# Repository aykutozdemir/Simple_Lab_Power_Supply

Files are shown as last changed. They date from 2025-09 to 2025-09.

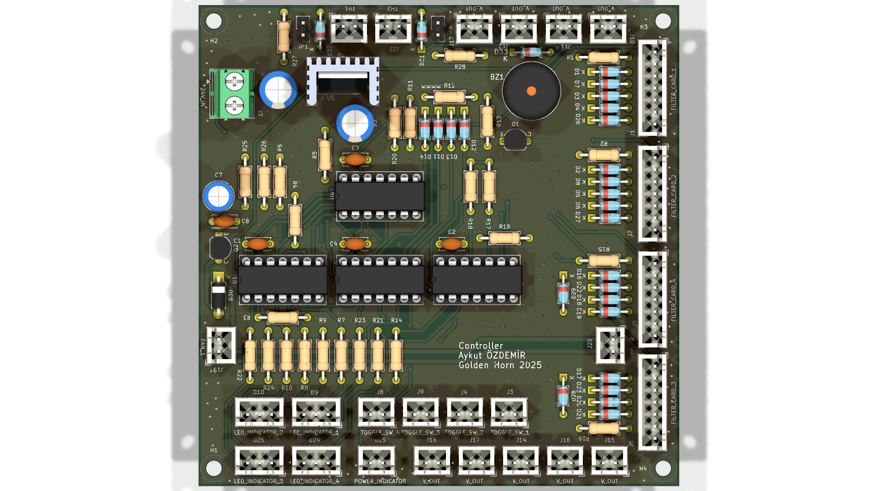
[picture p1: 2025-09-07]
Controller/generated/3d/Controller_3d_top.png

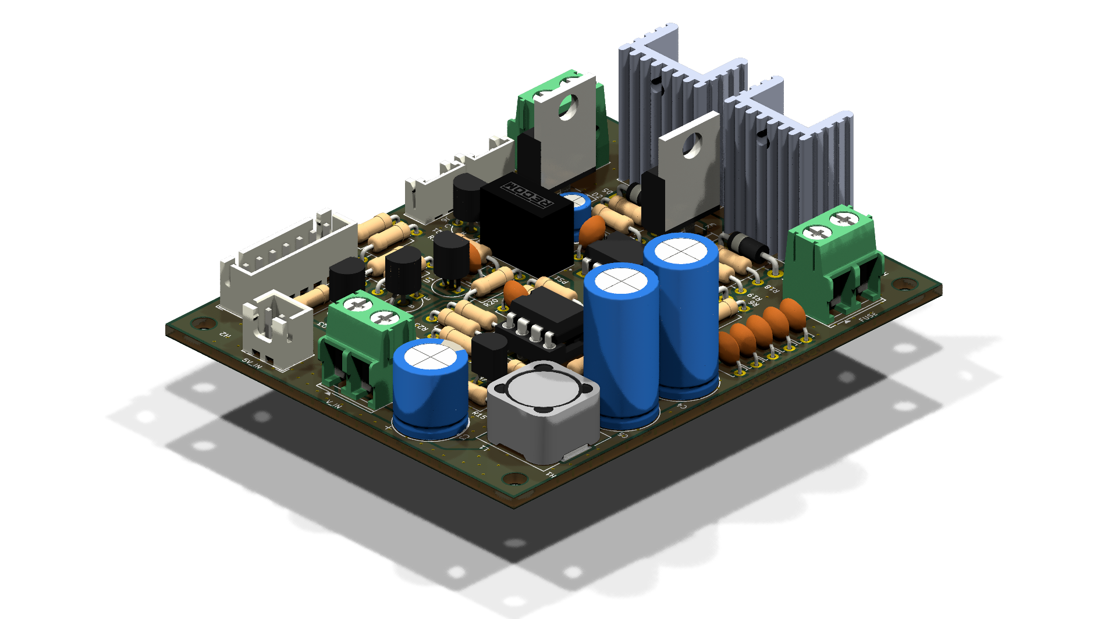
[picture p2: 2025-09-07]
Protection/generated/3d/Protection_3d_back-right-up.png

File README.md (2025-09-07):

### Simple Lab Power Supply (4-Channel)

A compact four-channel bench power supply project with dedicated controller, protection, and current-sensing boards, plus a printable enclosure and front panel components. Repository: [`aykutozdemir/Simple_Lab_Power_Supply`](https://github.com/aykutozdemir/Simple_Lab_Power_Supply).

### Features
- **Four independent channels**: adjustable and monitorable per-channel output
- **Dedicated protection**: over-current/short-circuit protection board
- **Current sensing**: separate current sensor design for precise measurement
- **Printable enclosure**: parametric SCAD and exported STLs for all case parts
- **Fabrication-ready**: gerbers, BOMs, PDFs, and 3D previews included

### Repository layout
- `Controller/`: KiCad project for the main control PCB
  - `generated/gerbers/`: fabrication files
  - `generated/bom/`: BOM in CSV/HTML/PDF
  - `generated/pdf/`: PCB and schematic PDFs
  - `generated/3d/`: 3D renders and board STEP/STL
- `Protection/`: KiCad project for the protection PCB
  - `generated/` mirrors the structure above
- `Current_Sensor/`: KiCad project for the current sensor
- `3D/`: mechanical assets and enclosure
  - `exports/`: printable panels and enclosure parts (`front.stl`, `back.stl`, `left.stl`, `right.stl`, `top.stl`, `bottom.stl`, `mid.stl`)
  - subfolders for off-the-shelf or custom components (banana jacks, fan, sockets, switches, knobs, etc.)

### Quick start
1) Open electronics in KiCad (KiCad 7+ recommended):
   - `Controller/Controller.kicad_pro`
   - `Protection/Protection.kicad_pro`
   - `Current_Sensor/Current_Sensor.kicad_pro`
2) Fabrication files:
   - Controller gerbers: `Controller/generated/gerbers/`
   - Protection gerbers: `Protection/generated/gerbers/`
   - BOMs: `Controller/generated/bom/Controller_bom.*`, `Protection/generated/bom/Protection_bom.*`
   - PDFs (schematic/PCB): see `generated/pdf/`
3) Enclosure and front panel:
   - Print from `3D/exports/*.stl`
   - Optional components located in subfolders (e.g., `3D/banana/banana.stl`, `3D/pot/pot.stl`, `3D/fan/fan.stl`)

### 3D printing guidance
- Material: PLA or PETG (PETG recommended for heat resistance)
- Layer height: 0.2 mm (typ.)
- Infill: 15–25% grid/gyroid for panels; 35–50% for brackets
- Walls: 3–4 perimeters; 4–6 top/bottom layers
- Orientation: print panels flat; brackets with load-bearing axis aligned; check STL previews in `3D/exports/`

### Front panel notes
- Displays and meters mount to the `front.stl` panel. Matching cutouts are modeled in the exported panel.
- Banana connectors: use `3D/banana/banana.stl`. In the assembled view, place two banana connectors per multimeter, horizontally below the displays, visible from front. Front panel hole x-offsets at ±12 mm and z at `box_height*4/6 - multimeter_height/2 - 25`. Place connectors at y slightly in front of the front panel (e.g., `box_depth + 1`) and rotate `[-90, 0, 0]` for insertion alignment [[memory:6634135]].

### Electrical overview
- Controller board manages channel outputs, measurement, and user interface.
- Protection board implements fast over-current/short protection and isolation where needed.
- Current sensor board provides per-channel current measurement with appropriate scaling.
- See the comprehensive PDFs in `Controller/generated/pdf/` and `Protection/generated/pdf/` for signal names and interfaces.

### Fabrication and assembly
1) Order PCBs using the gerbers in each project’s `generated/gerbers/` directory.
2) Source parts from the BOMs (`generated/bom/`). Check packages/footprints against PDFs.
3) Solder SMD/TH components as per schematics.
4) Test each board independently before system integration.
5) Assemble enclosure:
   - Dry-fit `front`, `back`, `left`, `right`, `top`, `bottom`, and `mid` panels.
   - Install switches, sockets, fuses, fan, pots/knobs, and banana jacks.
   - Route wiring according to schematics; keep high-current and low-noise paths separated.

### Safety
- Mains voltages and high currents can be hazardous. Verify isolation, fusing, and protective earth where applicable.
- Use appropriate gauge wiring, strain relief, and insulation. Validate thermal performance under load.

### Contributing
- Issues and pull requests are welcome on GitHub: `https://github.com/aykutozdemir/Simple_Lab_Power_Supply`.
- For changes that affect the enclosure, export updated STLs to `3D/exports/` and include screenshots/renders.
- For PCB edits, regenerate `generated/` assets (BOM, PDFs, gerbers) so reviewers can diff artifacts.

### License
No license file is included yet. If you intend to reuse or distribute, please open an issue to clarify licensing, or add a `LICENSE` file.

### Credits
Design and repository maintained by Aykut Ozdemir. See the GitHub repository for history and updates: [`Simple_Lab_Power_Supply`](https://github.com/aykutozdemir/Simple_Lab_Power_Supply).

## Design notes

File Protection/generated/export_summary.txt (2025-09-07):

KiCad Export Summary
===================
Project: Protection
Export Date: Sun Sep  7 02:46:42 PM +03 2025
Output Folder: generated

Generated Files:
================
  3d/Protection_3d_back-left.png
  3d/Protection_3d_back-left-up.png
  3d/Protection_3d_back.png
  3d/Protection_3d_back-right.png
  3d/Protection_3d_back-right-up.png
  3d/Protection_3d_bottom-left.png
  3d/Protection_3d_bottom.png
  3d/Protection_3d_bottom-right.png
  3d/Protection_3d_front-left.png
  3d/Protection_3d_front-left-up.png
  3d/Protection_3d_front.png
  3d/Protection_3d_front-right.png
  3d/Protection_3d_front-right-up.png
  3d/Protection_3d_left.png
  3d/Protection_3d_right.png
  3d/Protection_3d_top-left.png
  3d/Protection_3d_top-left-up.png
  3d/Protection_3d_top.png
  3d/Protection_3d_top-right.png
  3d/Protection_3d_top-right-up.png
  3d/Protection_board.step
  3d/Protection_board.stl
  3d/Protection_full.step
  3d/Protection_full.stl
  bom/Protection_bom.csv
  bom/Protection_bom.html
  bom/Protection_bom.pdf
  export_summary.txt
  gerbers/Protection-B_Adhesive.gba
  gerbers/Protection-B_Courtyard.gbr
  gerbers/Protection-B_Cu.gbl
  gerbers/Protection-B_Fab.gbr
  gerbers/Protection-B_Mask.gbs
  gerbers/Protection-B_Paste.gbp
  gerbers/Protection-B_Silkscreen.gbo
  gerbers/Protection.drl
  gerbers/Protection-Edge_Cuts.gm1
  gerbers/Protection-F_Adhesive.gta
  gerbers/Protection-F_Courtyard.gbr
  gerbers/Protection-F_Cu.gtl
  gerbers/Protection-F_Fab.gbr
  gerbers/Protection-F_Mask.gts
  gerbers/Protection-F_Paste.gtp
  gerbers/Protection-F_Silkscreen.gto
  gerbers/Protection_gerbers.zip
  gerbers/Protection-job.gbrjob
  gerbers/Protection-Margin.gbr
  gerbers/Protection-User_1.gbr
  gerbers/Protection-User_2.gbr
  gerbers/Protection-User_3.gbr
  gerbers/Protection-User_4.gbr
  gerbers/Protection-User_Comments.gbr
  gerbers/Protection-User_Drawings.gbr
  gerbers/Protection-User_Eco1.gbr
  gerbers/Protection-User_Eco2.gbr
  pdf/pcb/Protection_B.Cu.pdf
  pdf/pcb/Protection_B.SilkS.pdf
  pdf/pcb/Protection_F.Cu.pdf
  pdf/pcb/Protection_F.SilkS.pdf
  pdf/Protection_comprehensive.pdf
  pdf/schematic/Protection.pdf

Folder Structure:
=================
/home/aykut/Dropbox/Developments/KiCad/Simple_Lab_Power_Supply/Protection/generated
  3d
  bom
  gerbers
  pdf
  pdf/pcb
  pdf/schematic

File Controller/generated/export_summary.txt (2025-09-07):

KiCad Export Summary
===================
Project: Controller
Export Date: Wed Aug 27 04:48:48 PM +03 2025
Output Folder: generated

Generated Files:
================
  3d/Controller_3d_back-left.png
  3d/Controller_3d_back-left-up.png
  3d/Controller_3d_back.png
  3d/Controller_3d_back-right.png
  3d/Controller_3d_back-right-up.png
  3d/Controller_3d_bottom-left.png
  3d/Controller_3d_bottom.png
  3d/Controller_3d_bottom-right.png
  3d/Controller_3d_front-left.png
  3d/Controller_3d_front-left-up.png
  3d/Controller_3d_front.png
  3d/Controller_3d_front-right.png
  3d/Controller_3d_front-right-up.png
  3d/Controller_3d_left.png
  3d/Controller_3d_right.png
  3d/Controller_3d_top-left.png
  3d/Controller_3d_top-left-up.png
  3d/Controller_3d_top.png
  3d/Controller_3d_top-right.png
  3d/Controller_3d_top-right-up.png
  3d/Controller_board.step
  3d/Controller_board.stl
  3d/Controller_full.step
  3d/Controller_full.stl
  bom/Controller_bom.csv
  bom/Controller_bom.html
  bom/Controller_bom.pdf
  export_summary.txt
  gerbers/Controller-B_Adhesive.gba
  gerbers/Controller-B_Courtyard.gbr
  gerbers/Controller-B_Cu.gbl
  gerbers/Controller-B_Fab.gbr
  gerbers/Controller-B_Mask.gbs
  gerbers/Controller-B_Paste.gbp
  gerbers/Controller-B_Silkscreen.gbo
  gerbers/Controller.drl
  gerbers/Controller-Edge_Cuts.gm1
  gerbers/Controller-F_Adhesive.gta
  gerbers/Controller-F_Courtyard.gbr
  gerbers/Controller-F_Cu.gtl
  gerbers/Controller-F_Fab.gbr
  gerbers/Controller-F_Mask.gts
  gerbers/Controller-F_Paste.gtp
  gerbers/Controller-F_Silkscreen.gto
  gerbers/Controller_gerbers.zip
  gerbers/Controller-job.gbrjob
  gerbers/Controller-Margin.gbr
  gerbers/Controller-User_1.gbr
  gerbers/Controller-User_2.gbr
  gerbers/Controller-User_3.gbr
  gerbers/Controller-User_4.gbr
  gerbers/Controller-User_Comments.gbr
  gerbers/Controller-User_Drawings.gbr
  gerbers/Controller-User_Eco1.gbr
  gerbers/Controller-User_Eco2.gbr
  pdf/Controller_comprehensive.pdf
  pdf/pcb/Controller_B.Cu.pdf
  pdf/pcb/Controller_B.SilkS.pdf
  pdf/pcb/Controller_F.Cu.pdf
  pdf/pcb/Controller_F.SilkS.pdf
  pdf/schematic/Controller.pdf

Folder Structure:
=================
/home/aykut/Dropbox/Developments/KiCad/Simple_Lab_Power_Supply/Controller/generated
  3d
  bom
  gerbers
  pdf
  pdf/pcb
  pdf/schematic

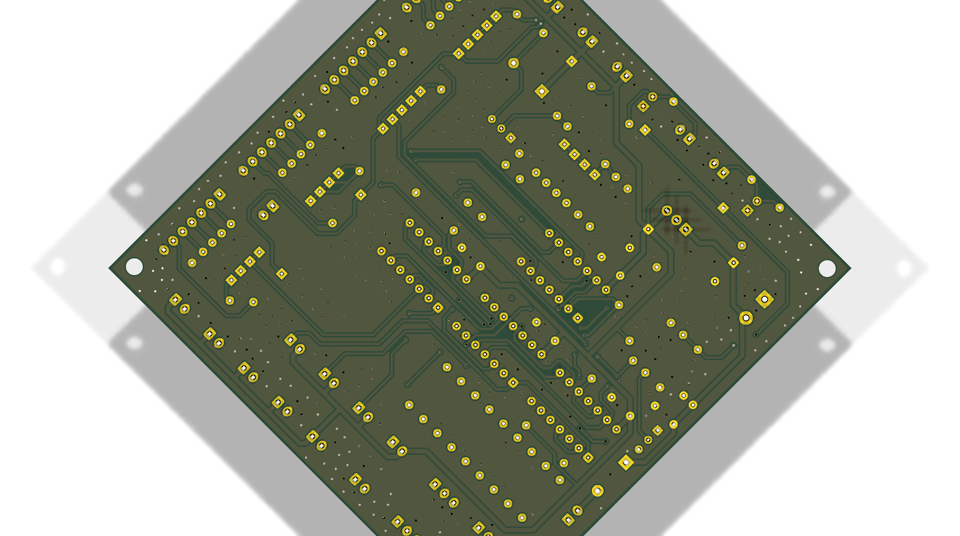
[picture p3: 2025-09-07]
Controller/generated/3d/Controller_3d_bottom-left.png

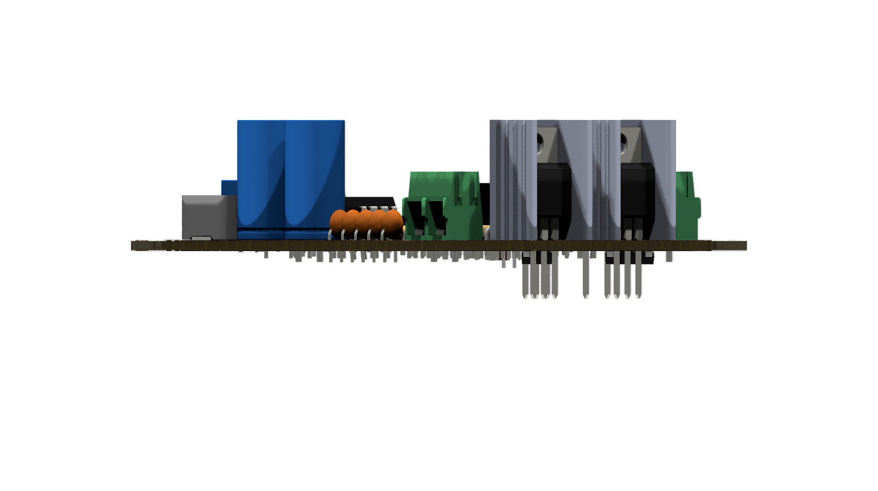
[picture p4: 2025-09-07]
Protection/generated/3d/Protection_3d_front-left.png

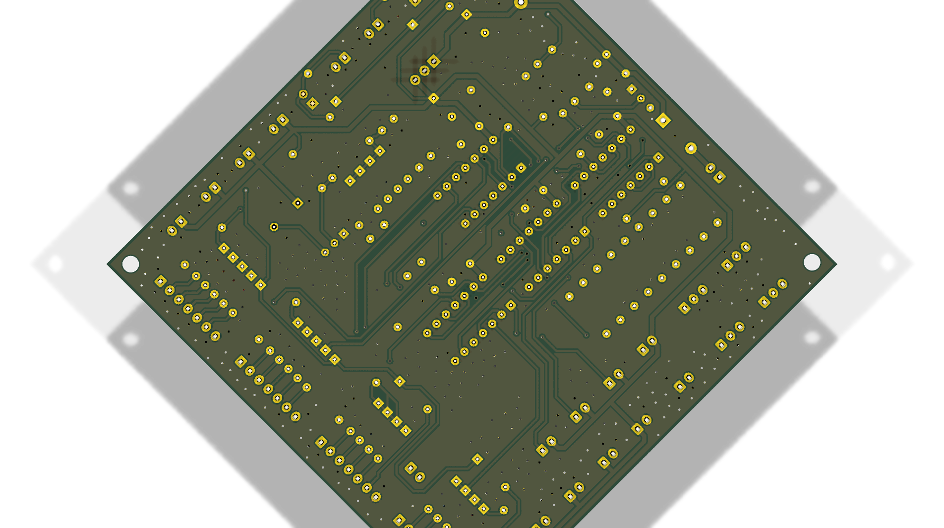
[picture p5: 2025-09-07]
Controller/generated/3d/Controller_3d_bottom-right.png

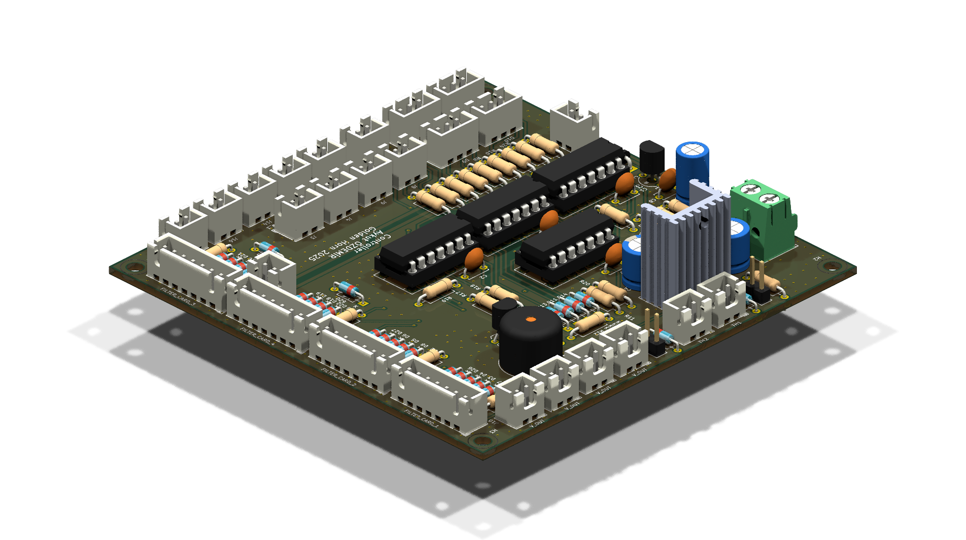
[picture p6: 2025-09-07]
Controller/generated/3d/Controller_3d_back-left-up.png

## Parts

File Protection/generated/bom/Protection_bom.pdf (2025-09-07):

# Bill of Materials

## Protection

Export Date: Sun Sep 7 02:46:40 PM +03 2025 | Total Components: 44
Reference | Value | Footprint | Quantity | Rating/Spec
C10 | 100p | Capacitor_THT:C_Disc_D5.0mm_W2.5mm_P5.00mm | 1 | 50V
C9 | 1n | Capacitor_THT:C_Disc_D5.0mm_W2.5mm_P5.00mm | 1 | 50V
C8 | 10n | Capacitor_THT:C_Disc_D5.0mm_W2.5mm_P5.00mm | 1 | 50V
C1,C2,C7,C11,C13,C15 | 100n | Capacitor_THT:C_Disc_D5.0mm_W2.5mm_P5.00mm | 6 | 50V
C6 | 1u | Capacitor_THT:C_Disc_D5.0mm_W2.5mm_P5.00mm | 1 | 50V
C14 | 100u | Capacitor_THT:CP_Radial_D5.0mm_P2.50mm | 1 | 25V
C3 | 330u | Capacitor_THT:CP_Radial_D10.0mm_P5.00mm | 1 | 50V
C4,C5 | 470u | Capacitor_THT:C_Radial_D10.0mm_H20.0mm_P5.00mm | 2 | 50V
J3 | 5V_IN | Connector_JST:JST_XH_B2B-XH-A_1x02_P2.50mm_Vertical | 1
F1 | 10A | TerminalBlock_Phoenix:TerminalBlock_Phoenix_PT-1,5-2-5.0-H_1x02_P5.00mm_Horizontal | 1
R19,R21 | 10 | Resistor_THT:R_Axial_DIN0207_L6.3mm_D2.5mm_P10.16mm_Horizontal | 2
D3,D5 | 15V | Diode_THT:D_DO-41_SOD81_P10.16mm_Horizontal | 2
R11 | 120 | Resistor_THT:R_Axial_DIN0207_L6.3mm_D2.5mm_P10.16mm_Horizontal | 1
R20 | 270 | Resistor_THT:R_Axial_DIN0207_L6.3mm_D2.5mm_P10.16mm_Horizontal | 1
R1,R6,R10,R12,R13,R15,R17 | 1k | Resistor_THT:R_Axial_DIN0207_L6.3mm_D2.5mm_P10.16mm_Horizontal | 7
R7,R8 | 10k | Resistor_THT:R_Axial_DIN0207_L6.3mm_D2.5mm_P10.16mm_Horizontal | 2 | %1
R14,R16,R22,R24 | 10k | Resistor_THT:R_Axial_DIN0207_L6.3mm_D2.5mm_P10.16mm_Horizontal | 4
R9,R18 | 47k | Resistor_THT:R_Axial_DIN0207_L6.3mm_D2.5mm_P10.16mm_Horizontal | 2
R23 | 100k | Resistor_THT:R_Axial_DIN0207_L6.3mm_D2.5mm_P10.16mm_Horizontal | 1
R25 | 0/0/0/10k | Resistor_THT:R_Axial_DIN0207_L6.3mm_D2.5mm_P10.16mm_Horizontal | 1 | %1
R5 | 150k/150k/100k/3V Zener | Resistor_THT:R_Axial_DIN0207_L6.3mm_D2.5mm_P10.16mm_Horizontal | 1 | %1
R2 | 150k/150k/130k/33k | Resistor_THT:R_Axial_DIN0207_L6.3mm_D2.5mm_P10.16mm_Horizontal | 1 | %1
Q1,Q3-Q5 | 2N3904 | PCM_Package_TO_SOT_THT_AKL:TO-92_Inline_Wide_EBC | 4
D4 | 3.9V/5.6V/13V/27V | Diode_THT:D_DO-41_SOD81_P10.16mm_Horizontal | 1
R4 | 30k/120k/330k/1k | Resistor_THT:R_Axial_DIN0207_L6.3mm_D2.5mm_P10.16mm_Horizontal | 1 | %1

Bill of Materials - Protection

Reference | Value | Footprint | Quantity | Rating/Spec
C12 | 4u7 | Capacitor_SMD:C_1206_3216Metric_Pad1.33x1.80mm_HandSolder | 1 | 50V
L1 | 4u7 | Inductor_SMD:L_12x12mm_H8mm | 1 | 15A
R3 | 68k/180k/560k/330k | Resistor_THT:R_Axial_DIN0207_L6.3mm_D2.5mm_P10.16mm_Horizontal | 1 | %1
Q2 | BT152-800R | PCM_Package_TO_SOT_THT_AKL:TO-220-3_Vertical_KAG | 1
HS1,HS2 | Heatsink | Power_Module_Library:TO-220_Heatsink | 2
Q6,Q8 | IRF1404/IRFB4110 | PCM_Package_TO_SOT_THT_AKL:TO-220-3_Vertical_GDS | 2
J2,J6 | JST_02 | Connector_JST:JST_EH_B2B-EH-A_1x02_P2.50mm_Vertical | 2
J5 | JST_07 | Connector_JST:JST_XH_B7B-XH-A_1x07_P2.50mm_Vertical | 1
U2 | LM393 | PCM_Package_DIP_AKL:DIP-8_W7.62mm_Socket | 1
D2 | MBR1045 | PCM_Package_TO_SOT_THT_AKL:TO-220-2_Vertical_KA | 1
R26 | NC/NC/NC/3k9 | Resistor_THT:R_Axial_DIN0207_L6.3mm_D2.5mm_P10.16mm_Horizontal | 1 | %1
PS1 | ROE-0515S | Isolation_Trafo:CONV_ROE-0515S | 1
D1 | SMAJ5.0A/6.0A/13.0A/26A | PCM_Diode_SMD_AKL:D_SMA | 1
D6 | SMAJ5.0A/6.0A/18.0A/30A | PCM_Diode_SMD_AKL:D_SMA | 1
D7 | SMAJ5.0A/6.0A/18.0A/33A | PCM_Diode_SMD_AKL:D_SMA | 1
U1 | TL431LP | Package_TO_SOT_THT:TO-92_Inline | 1
U3 | TLP250 | Package_DIP:DIP-8_W7.62mm | 1
J1 | V_IN | TerminalBlock_Phoenix:TerminalBlock_Phoenix_PT-1,5-2-5.0-H_1x02_P5.00mm_Horizontal | 1
J4 | V_OUT | TerminalBlock_Phoenix:TerminalBlock_Phoenix_PT-1,5-2-5.0-H_1x02_P5.00mm_Horizontal | 1
Generated by KiCad Export System | Professional BOM Documentation

Bill of Materials - Protection

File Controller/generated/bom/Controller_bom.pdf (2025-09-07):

# Bill of Materials

## Controller

Export Date: Wed Aug 27 04:48:46 PM +03 2025 | Total Components: 26
Reference | Value | Footprint | Quantity | Rating/ Spec
C6 | 0.1u | Capacitor_THT:CP_Radial_Tantal_D5.5mm_P5.00mm | 1 | 63V
C1-C4,C8 | 100n | Capacitor_THT:C_Disc_D5.0mm_W2.5mm_P5.00mm | 5 | 50V
C5 | 0.33u | Capacitor_THT:CP_Radial_Tantal_D5.5mm_P5.00mm | 1 | 50V
C7 | 47u | Capacitor_THT:C_Radial_D6.3mm_H11.0mm_P2.50mm | 1 | 50V
R7-R10,R14,R21-R24 | 470 | Resistor_THT:R_Axial_DIN0207_L6.3mm_D2.5mm_P10.16mm_Horizontal | 9 | %1
R26 | 820 | Resistor_THT:R_Axial_DIN0207_L6.3mm_D2.5mm_P10.16mm_Horizontal | 1
R12 | 1k | Resistor_THT:R_Axial_DIN0207_L6.3mm_D2.5mm_P10.16mm_Horizontal | 1
R1,R2,R11,R13,R15,R16,R25 | 10k | Resistor_THT:R_Axial_DIN0207_L6.3mm_D2.5mm_P10.16mm_Horizontal | 7
R3-R6,R17-R20 | 10k | Resistor_THT:R_Axial_DIN0207_L6.3mm_D2.5mm_P10.16mm_Horizontal | 8 | %1
D30 | 1N4001 | PCM_Diode_THT_AKL:D_DO-41_SOD81_P7.62mm_Horizontal | 1
D1-D8,D11-D14,D16-D23,D26-D29,D31-D33 | 1N4148 | PCM_Diode_THT_AKL:D_DO-35_SOD27_P7.62mm_Horizontal | 27
Q1 | 2N3904 | PCM_Package_TO_SOT_THT_AKL:TO-92_Inline_Wide_EBC | 1
Q2 | 2N4401 | PCM_Package_TO_SOT_THT_AKL:TO-92_Inline_Wide_EBC | 1
R27,R28 | 4k7 | Resistor_THT:R_Axial_DIN0207_L6.3mm_D2.5mm_P10.16mm_Horizontal | 2
U3 | 74LS08 | Package_DIP:DIP-14_W7.62mm_Socket | 1
U1,U2 | 74LS74 | Package_DIP:DIP-14_W7.62mm_Socket | 2
U4 | 74LS86 | Package_DIP:DIP-14_W7.62mm_Socket | 1
BZ1 | Buzzer_5V | Buzzer_Beeper:Buzzer_12x9.5RM7.6 | 1
HS1 | Heatsink_Generic | Power_Module_Library:TO-220_Heatsink | 1
J3,J4,J8-J22 | JST_02 | Connector_JST:JST_XH_B2B-XH-A_1x02_P2.50mm_Vertical | 17
J1,J2,J5,J6 | JST_07 | Connector_JST:JST_XH_B7B-XH-A_1x07_P2.50mm_Vertical | 4
U5 | L7805CV | PCM_Package_TO_SOT_THT_AKL:TO-220-3_Vertical | 1
D15 | LED_5mm | Connector_JST:JST_XH_B2B-XH-A_1x02_P2.50mm_Vertical | 1
D9,D10,D24,D25 | LED_Dual_AKA | Connector_JST:JST_XH_B3B-XH-A_1x03_P2.50mm_Vertical | 4

Bill of Materials - Controller

Reference | Value | Footprint | Quantity | Rating/ Spec
J7 | Screw_Terminal_2_P5.00mm | TerminalBlock_Phoenix:TerminalBlock_Phoenix_PT-1,5-2-5.0-H_1x02_P5.00mm_Horizontal | 1
JP1,JP2 | ~ | Connector_PinHeader_2.54mm:PinHeader_1x02_P2.54mm_Vertical | 2
Generated by KiCad Export System | Professional BOM Documentation

Bill of Materials - Controller

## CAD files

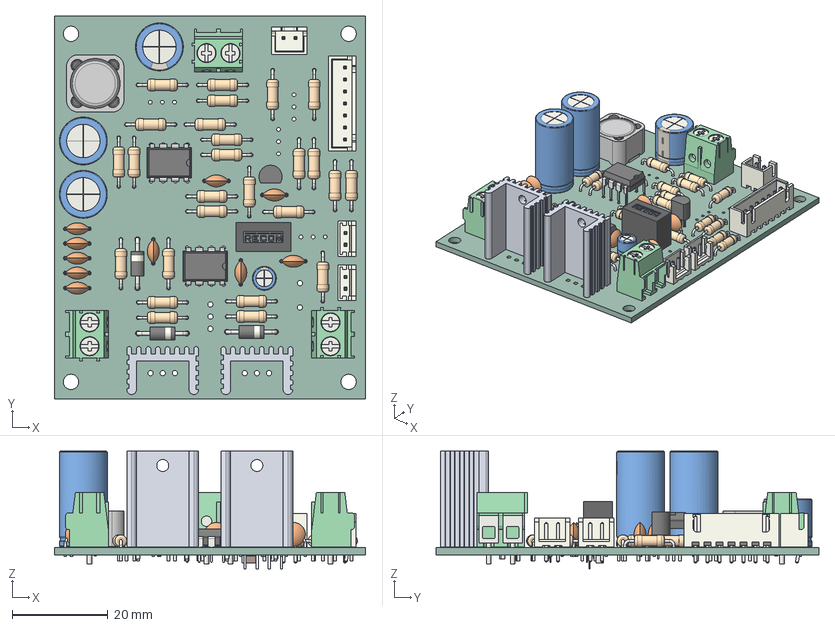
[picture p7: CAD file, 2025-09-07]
Protection/generated/3d/Protection_full.step
65.0 x 80.0 x 24.6 mm
D_DO-41_SOD81_P10.16mm_Horizontal x 3
CP_Radial_D10.0mm_P5.00mm
R_Axial_DIN0207_L6.3mm_D2.5mm_P10.16mm_Horizontal x 26
C_Disc_D5.0mm_W2.5mm_P5.00mm x 10
ROE_case
ROE_pin4(+Vout)
ROE_pin1(-Vin)
ROE_pin3(-Vout)
ROE_pin2(+Vin)
ROE_potting
JST_EH_B2B-EH-A_1x02_P2.50mm_Vertical x 2
TO-92_Inline
C_Radial_D10.0mm_H20.0mm_P5.00mm x 2
DIP-8_W7.62mm x 2
TerminalBlock_Phoenix_PT-1,5-2-5.0-H_1x02_P5.00mm_Horizontal x 3
JST_XH_B7B-XH-A_1x07_P2.50mm_Vertical
CP_Radial_D5.0mm_P2.50mm
L_12x12mm_H8mm
JST_XH_B2B-XH-A_1x02_P2.50mm_Vertical
User Library-To-220-6 x 2
C_1206_3216Metric
Protection_PCB

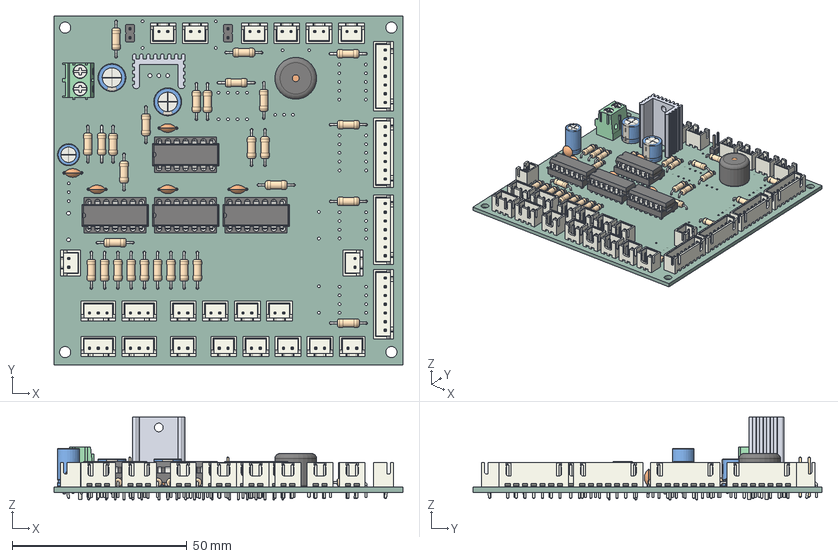
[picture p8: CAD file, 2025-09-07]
Controller/generated/3d/Controller_full.step
100.0 x 100.0 x 23.8 mm
R_Axial_DIN0207_L6.3mm_D2.5mm_P10.16mm_Horizontal x 28
DIP-14_W7.62mm_Socket x 4
DIP-14_W7.62mm x 4
JST_XH_B2B-XH-A_1x02_P2.50mm_Vertical x 18
JST_XH_B7B-XH-A_1x07_P2.50mm_Vertical x 4
User Library-To-220-6
JST_XH_B3B-XH-A_1x03_P2.50mm_Vertical x 4
TerminalBlock_Phoenix_PT-1,5-2-5.0-H_1x02_P5.00mm_Horizontal
PinHeader_1x02_P2.54mm_Vertical x 2
CP_Radial_D8.0mm_P5.00mm x 2
C_Disc_D5.0mm_W2.5mm_P5.00mm x 5
Buzzer_12x9.5RM7.6
C_Radial_D6.3mm_H11.0mm_P2.50mm
Controller_PCB

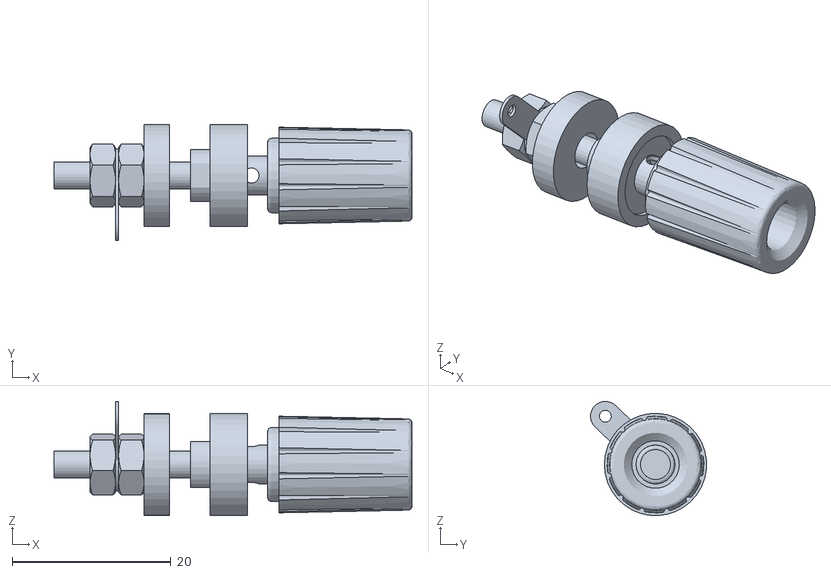
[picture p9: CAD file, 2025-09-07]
3D/banana/banana.stl
45.1 x 14.6 x 14.4

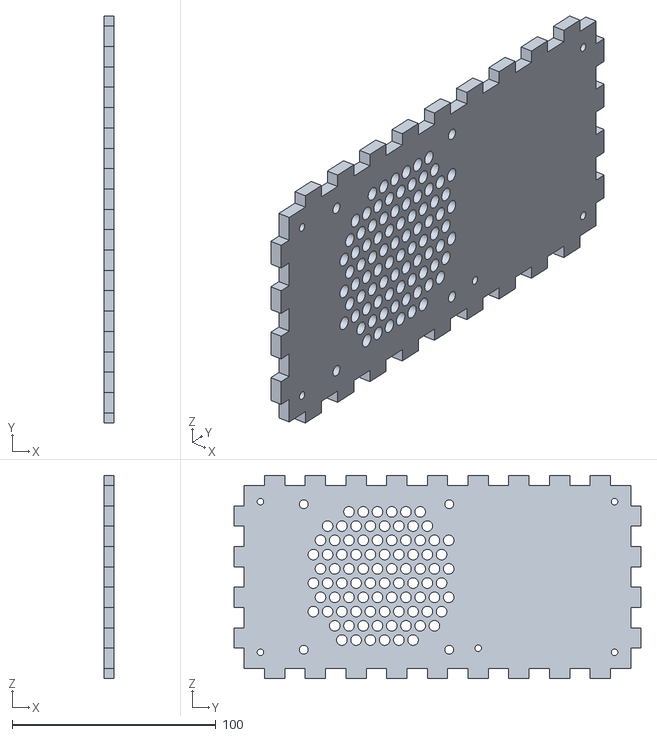
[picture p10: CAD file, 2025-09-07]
3D/exports/right.stl
5.00 x 200.0 x 100.0

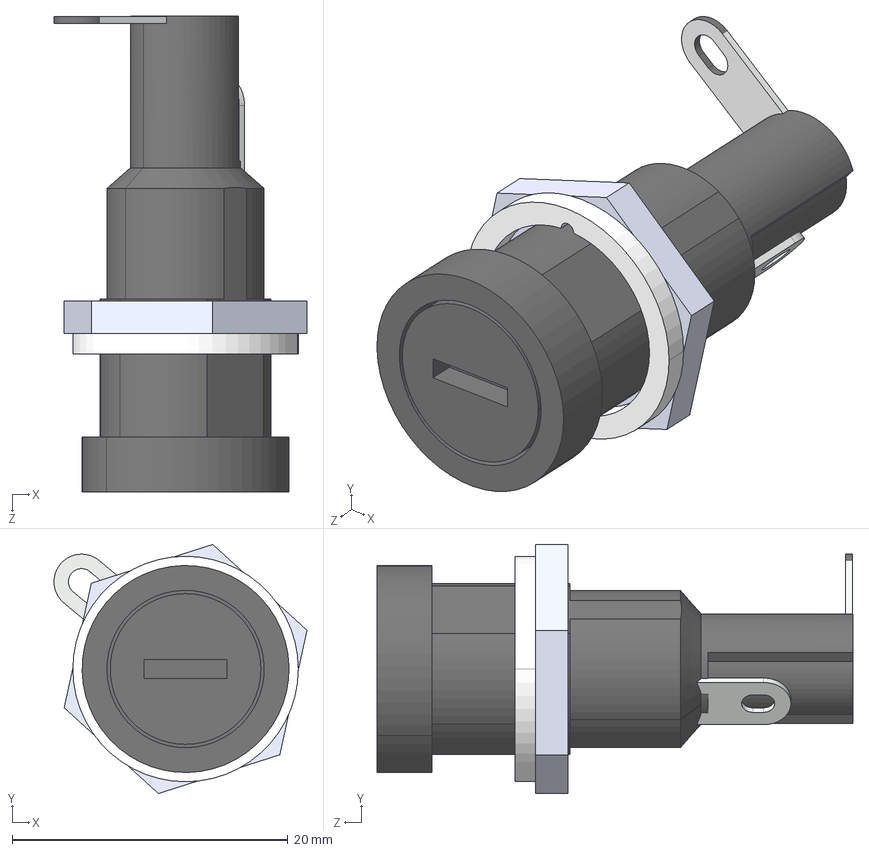
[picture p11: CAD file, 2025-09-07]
3D/fuse/KLS5-258 (FH-B02), Fuse holder 5,2E20.STEP
18.3 x 18.1 x 34.5 mm
housing
cap
plastic washer
Hexagon Nut

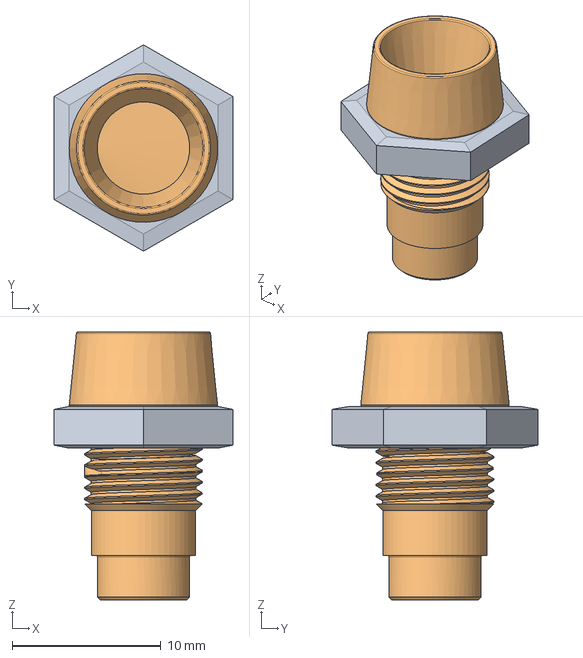
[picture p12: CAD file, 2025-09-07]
3D/led/LED holder 5mm.step
12.0 x 13.9 x 18.0 mm
M8 Kontermutter
Grundkörper

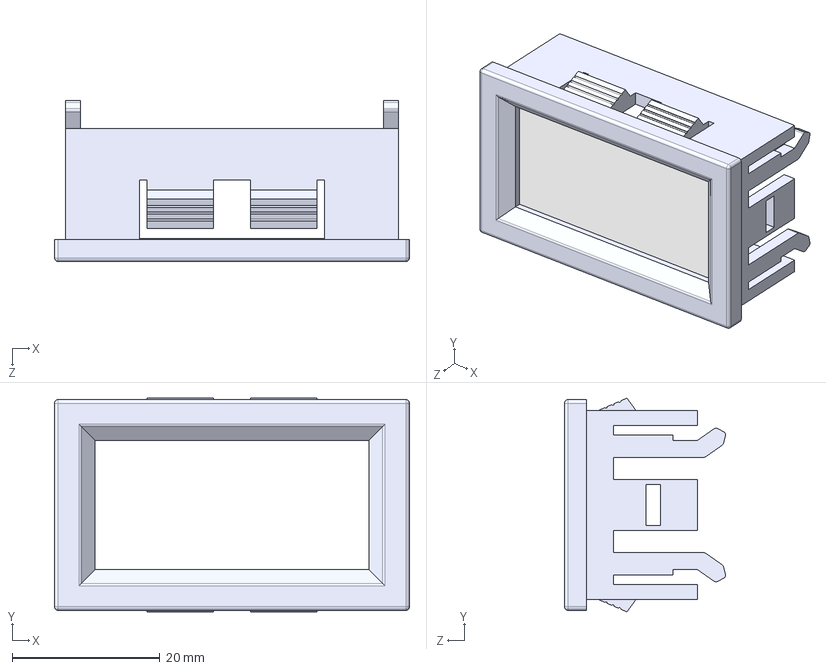
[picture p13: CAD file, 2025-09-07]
3D/multimeter/v & a metr.STEP
48.0 x 28.9 x 21.8 mm

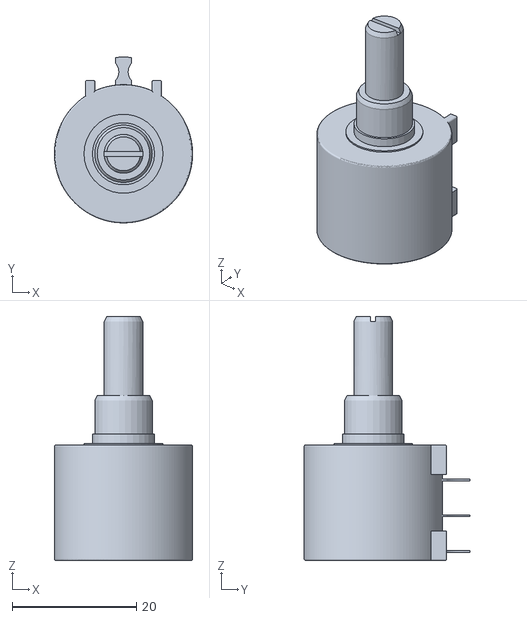
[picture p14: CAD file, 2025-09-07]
3D/pot/pot.stl
22.2 x 26.6 x 39.2

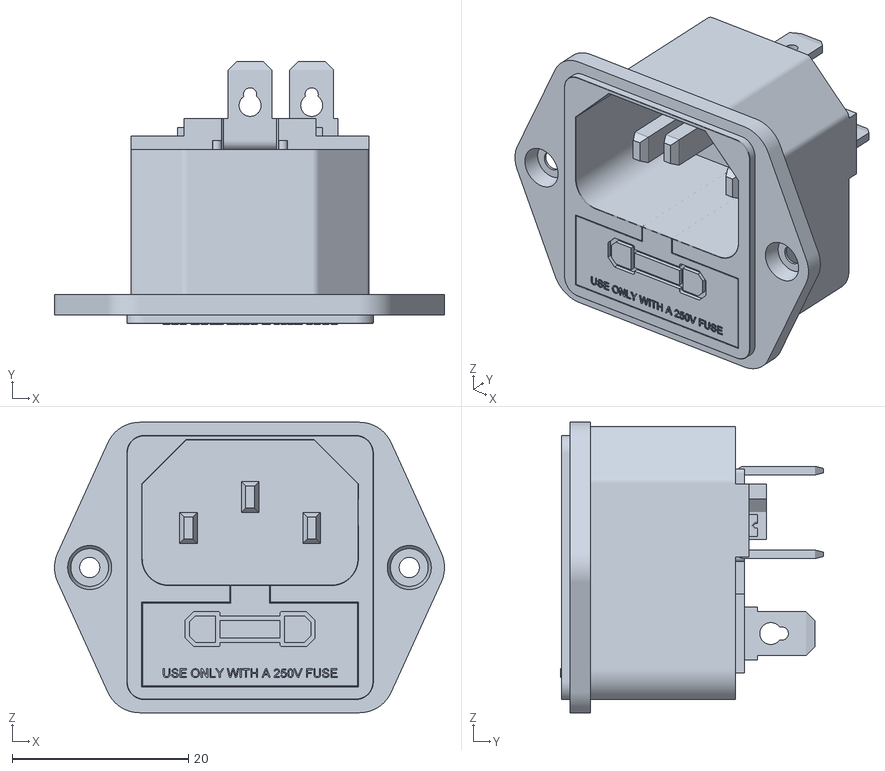
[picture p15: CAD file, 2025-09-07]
3D/socket/Shapes011.stl
44.3 x 29.9 x 33.0

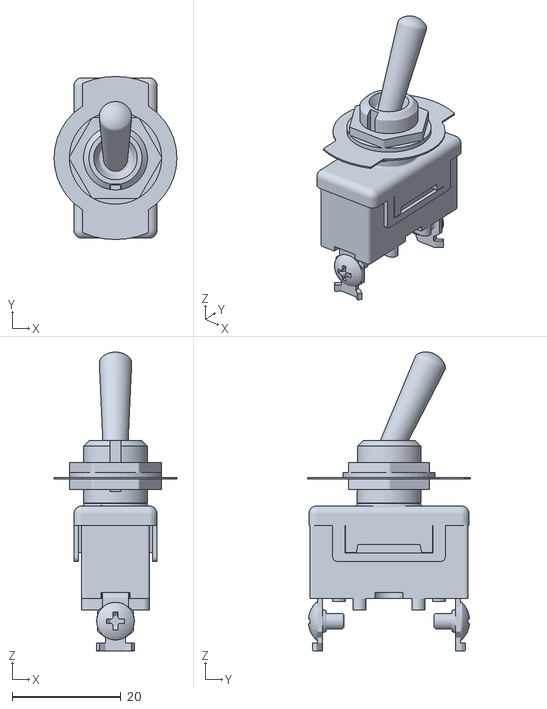
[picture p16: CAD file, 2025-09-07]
3D/switch/E-TEN 1021 On_Off Toggle Switch v7.stl
22.6 x 30.0 x 55.0

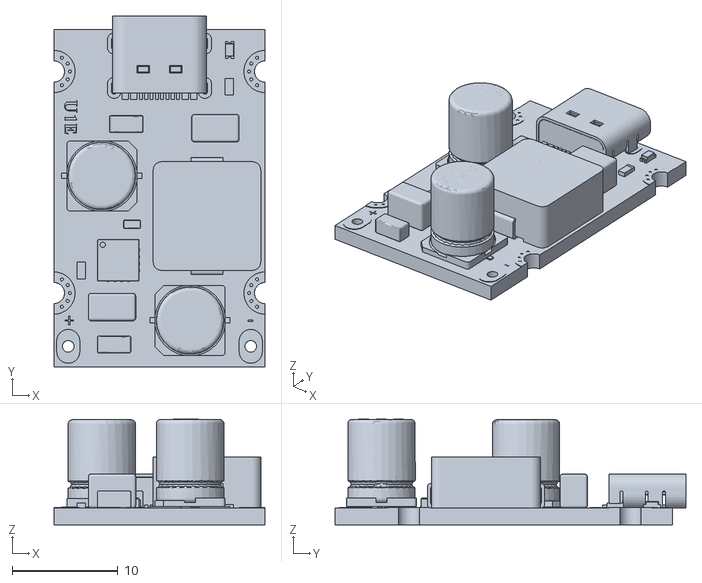
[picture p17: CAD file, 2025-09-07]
3D/usb/u1e.stl
20.0 x 33.2 x 10.0

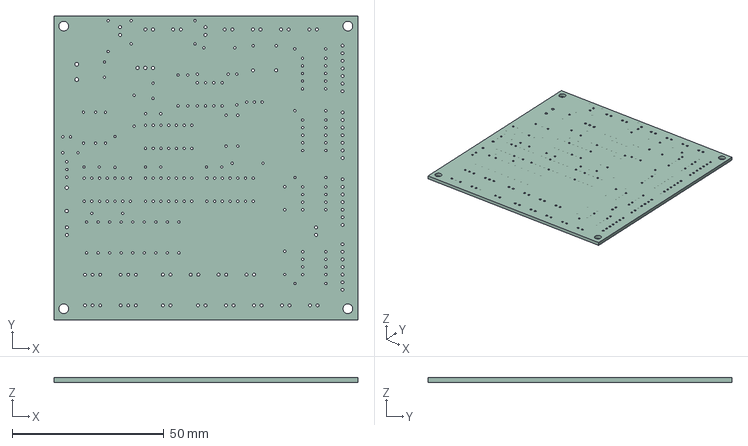
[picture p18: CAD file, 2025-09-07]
Controller/generated/3d/Controller_board.step
100.0 x 100.0 x 1.51 mm

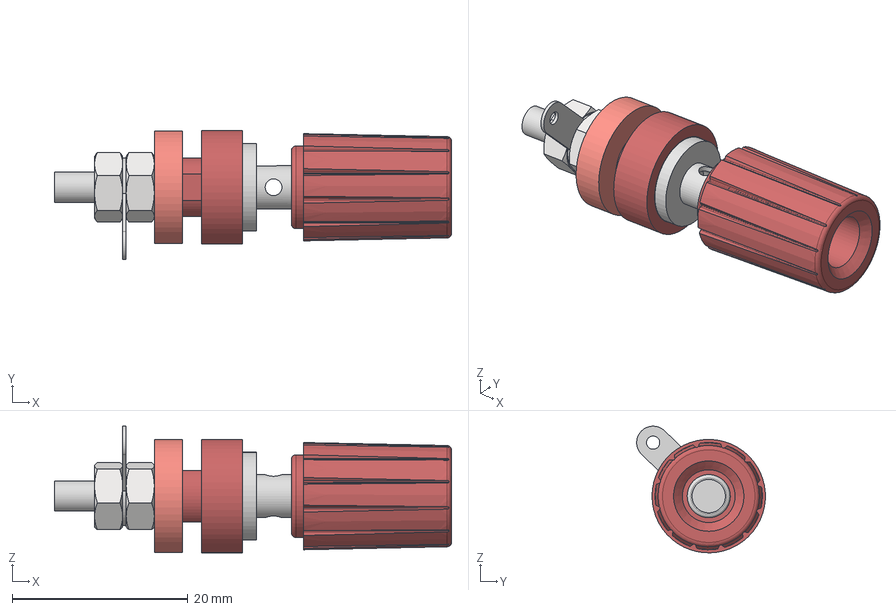
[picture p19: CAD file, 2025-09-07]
3D/banana/Banana jack (4mm).stp
45.1 x 14.6 x 14.4 mm
Metal rod
Front fixing part
Back washer
M4 nut x 2
4mm Banana Socket Terminal
solder_lug

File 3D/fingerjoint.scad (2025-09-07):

/* [Box Dimensions]*/
//X Dimension
xDim = 100;
//Y Dimension
yDim = 120;
//Z Dimension
zDim = 135;
//material thickness
material = 5;
//finger width
finger = 8;
//add debugging text
addText = 1; //[1:Add Text, 0:Do Not Add Text]

/*[Layout Type]*/
layout = "3D"; //[2D:2D for SVG output, 3D:3D for Visualization]

/*[Hidden]*/
//wierd bug in thingiverse customizer won't deal with boolean values so there's this hack
helpText = addText==1 ? true : false;

font = "Allerta Stencil";


/*
#Finger Joint Library
Created by Aaron Ciuffo aaron . ciuffo at gmail.

This library calculate the appropriate number of finger joints for joining laser cut parts 
given an edge length, material thickness and finger joint length. This is a **LIBRARY** 
to be used in other OpenSCAD projects when a finger join (also known as a box joint or 
comb joint) is needed between two faces.

To create a joint between faceA and faceB, faceA must have an insideCut() and faceB must
have an outsideCut() to properly align. 

*Note:* Finger length must be less than 1/3 the length of the edge to work properly.
If you see the warnings below in the OpenSCAD console, check your finger length 
values. Setting text=true will also provide useful visual debugging.
***DEPRECATED: Using ranges of the form [begin:end] with begin value greater than the end value is deprecated. 

A demonstration is also provided through module 2Dlayout() and 3Dlayout(). 

The thingiverse customizer will *not* yield proper STLS in 2D mode. The 3D models are not
proper either. 

This is derived from my previous Finger Joint Boxes.


###tl;dr usage:
use </path/to/fingerjoint.scad>
//cuts that fall entirely inside an edge
insideCuts(length = 204, finger = 10, material = 4.4);
//cuts that fall outside an edge
outsideCuts(length = 204, finger = 10, material = 4.4);
//2D layout demo
2Dlayout();
//3D layout demo
3Dlayout();

###Demo modules:
*Two Dimensional Layout*
- SVG EXPORT:  Render (F6), *File* > *Export* > *Export as SVG*
2DLayout();

*Three Dimensional Layout*
- For visualization only; this will not yield a proper STL for printing
3DLayout();

*Three Dimensional Layout with Face Control*
- Show only front and top faces:
3Dlayout(showBack = false, showBottom = false, showLeft = false, showRight = false);
- Show only internal view (no top):
3Dlayout(showTop = false);
- Show only bottom and sides:
3Dlayout(showTop = false, showFront = false, showBack = false);



##module: insideCuts
create a set of cuts that falls entirely inside the edge
  ###parameters:
    *length* (real)         length of edge
    *finger* (real)         length of each individual finger
    *material* (real)       thickness of material - sets cut depth
    *text* (boolean)           add help text to indicate cut type (for debugging)
    *center* (boolean)         center the set of fingers with respect to origin
      
##module: outsideCuts
Create a set of finger-joint cuts that result in two larger cuts taken at the outside 
edge 
  ###parameters:
    *length* (real)         length of edge
    *finger* (real)         length of each individual finger
    *material* (real)       thickness of material - sets cut depth
    *text* (boolean)           add help text to indicate cut type (for debugging)
    *center* (boolean)         center the set of fingers with respect to origin

##module 2Dlayout:
Create a 2D layout of demonstration box
  ###Parameters:
    *xDim* (real)             X dimension pf bpx
    *yDim* (real)             Y dimension of box
    *zDim* (real)             Z dimension of box
    *finger* (real)           length of each individual finger
    *material* (real)         thickness of material - sets cut depth
    *text* (boolean)          true: turns on help text to help identify cut type (debugging)

##module 3Dlayout:
Create a 3D layout of demonstration box
  ###Parameters:
    *xDim* (real)             X dimension pf bpx
    *yDim* (real)             Y dimension of box
    *zDim* (real)             Z dimension of box
    *finger* (real)           length of each individual finger
    *material* (real)         thickness of material - sets cut depth
    *text* (boolean)          true: turns on help text to help identify cut type (debugging)
*/


help_fingerjoint();

//uncomment for fun animation
$vpr = [$t * -360, $t * 360, $t * -360];


//demonstration modules
if (layout=="2D") {
  2Dlayout(xDim = xDim, yDim = yDim, zDim = zDim, finger = finger, material = material,
          text = helpText);
} 

if (layout=="3D") {
  3Dlayout(xDim = xDim, yDim = yDim, zDim = zDim, finger = finger, material = material,
          text = helpText);
}



module insideCuts(length = 100, finger = 8, material = 5, text = true, center = false) {
  // overage to ensure that all cuts are completed 
  o = 0.0001;


  //maximum possible divisions for this length
  maxDiv = floor(length/finger);
  //number of usable divisions that fall completely within the edge
  //for this implementation the number of divisions must be odd
  uDiv = maxDiv%2==0 ? maxDiv-3 : maxDiv-2; 
  
  // number of "female cuts"
  numCuts = ceil(uDiv/2);
 
  //echo("insideCuts\nmaxDiv", maxDiv, "\nuDiv", uDiv, "\nnumCuts", numCuts);

  xTrans = center==false ? 0 : -uDiv*finger/2;
  yTrans = center==false ? 0 : -material/2;
  
  translate([xTrans, yTrans]) {
    for (i=[0:numCuts-1]) {
      translate([i*finger*2, -o/2, 0]) //move the cuts slightly in y plane for complete cuts
        square([finger, material+o]); //add a small amount to ensure complete cuts
    }
  }
  debugText = finger>=length/3 ? "ERR: finger>1/3 length" : "insideCut";


  if (text) {
    translate([0, yTrans+material*2])
      text(text=debugText, size = length*0.05, halign = "center", font = font);
    //echo(debugText);
  }

}

module outsideCuts(length = 100, finger = 8, material = 5, text = false, center = false) {
  // overage to ensure that all cuts are completed 
  o = 0.0001;


  //maximum possible divisions for this length
  maxDiv = floor(length/finger);
  //number of usable divisions that fall completely within the edge
  //for this implentation the number of divisions must be odd
  uDiv = maxDiv%2==0 ? maxDiv-3 : maxDiv-2;
  
  // number of "female cuts"
  numCuts = floor(uDiv/2);

  //length of cut at either end
  endCut = (length-uDiv*finger)/2;

  padding = endCut + finger;
  //echo("outsideCuts\nmaxDiv", maxDiv, "\nuDiv", uDiv, "\nnumCuts", numCuts, "\nendCut", endCut);

  xTrans = center==false ? 0 : -(numCuts*2+1)*finger/2-endCut;
  yTrans = center==false ? 0 : -material/2;

  translate([xTrans, yTrans]) {
    // add the "endcut" for a standard width cut plus any residual
    square([endCut, material]);
    //create the standard fingers
    for (i=[0:numCuts]) {
      if(i < numCuts) {
        translate([i*finger*2+padding, -o/2]) //move the cuts slightly in y plane for overage
          square([finger, material+o]); //add a tiny amount to the material thickness 
      } else { // the last cut needs to be an end cut
        translate([i*finger*2+padding, -o/2])
          square([endCut, material+o]);
      }
    }
  }

  debugText = finger>=length/3 ? "ERR: finger>1/3 length" : "outsideCut";


  if (text) {
    translate([length/2+xTrans, yTrans+material*2])
    text(text=debugText, size = length*.05, halign = "center", font = font);
    //echo(debugText);
  }

}


module faceXY(xDim = 100, yDim = 100, finger = 8, material = 5, 
              center = false, text = true) {
  //create the YZ face

  //calculate the position of the X and Z displacement 
  xTrans = center==true ? 0 : xDim/2;
  yTrans = center==true ? 0 : yDim/2;

  // calculate the text size and rotation based on the dimensions
  textSize = xDim>=yDim ? xDim*.1 : yDim*.1;
  zRot = xDim>=yDim ? 0 : -90;

  // position the entire piece
  translate([xTrans, yTrans, 0]) {
    color("royalblue")
    // difference the fingers and text from the basic square
    difference() {
      square([xDim, yDim], center = true);

      if (text) {
        rotate([0, 0, zRot])
          text(text = "faceXY", size = textSize, halign = "center", 
              valign = "center", font = font);
      }

      for(i=[-1,1]) {
        //+/- X edges fingers
        translate([0, i*yDim/2+i*-material/2, 0])
          outsideCuts(length = xDim, finger = finger, material = material, text = text,
          center = true);
        //+/- Y edges fingers
        translate([i*xDim/2+i*-material/2, 0, 0])
          rotate([0, 0, 90])
          insideCuts(length = yDim, finger = finger, material = material, text = text,
          center = true);
      }

    }
  }
}


module faceYZ(yDim = 100, zDim = 100, finger = 8, material = 5, 
              center = false, text = true) {
  //create the YZ face

  //calculate the position of the X and Z displacement 

  yTrans = center==true ? 0 : yDim/2;
  zTrans = center==true ? 0 : zDim/2;
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

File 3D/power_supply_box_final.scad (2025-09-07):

// Power Supply Box Design
// Dimensions: 34cm width x 9cm height x 20cm depth
// Complete assembly with all components and cutouts

// Import finger joint library
use <fingerjoint.scad>;

// Box dimensions
box_width = 340;  // 34cm
box_height = 100;  // 10cm  
box_depth = 200;  // 20cm
wall_thickness = 5; // 5mm wall thickness

// Finger joint parameters
finger_width = 10; // Width of each finger

// Use the triangular corner module
use <tri_corner/triangle_corner.scad>;

// Import L bracket module
use <bracket/l_bracket.scad>;

// Potentiometer parameters
pot_hole_diameter = 10;
pot_vertical_gap = 30;

// Rocker switch parameters (single mount)
rocker_cutout_w = 12;    // panel cutout width (mm)
rocker_cutout_h = 30;    // panel cutout height (mm)
rocker_body_depth = 20;  // body depth into the box (mm)
use_rocker_stl = true;  // set true if you add an STL at rocker_stl_path
rocker_stl_path = "switch/Tekli-Montaj_Shrinkwrap_1.stl"; // expected STL path if available
rocker_front_offset = 0.5; // small protrusion beyond panel front (mm)

// Multimeter dimensions
multimeter_width = 46;
multimeter_height = 27;
multimeter_depth = 20;

// Internal PSU (rectangular prism) and standoffs
psu_length = 215;   // along X (mm)
psu_width  = 115;   // along Y (mm)
psu_height = 50;    // along Z (mm)
standoff_height = 3; // 0.5 cm standoff height (mm)
standoff_radius = 5;  // standoff outer radius (mm)
// Mounting hole pattern relative to PSU local origin (0,0 at PSU min X/Y corner)
// Four mount points uniformly 32.5 mm from each edge
psu_hole_margin_x = 32.5; // distance from PSU X edges to hole centers (mm)
psu_hole_margin_y = 32.5; // distance from PSU Y edges to hole centers (mm)
// Clearance radius for M4 screw
m4_clearance_r = 2.2;   // ~4.4 mm diameter

// Rear socket cutout (for socket/Shapes011.stl)
rear_socket_cutout_w = 27; // mm (adjust as needed)
rear_socket_cutout_h = 31; // mm (adjust as needed)
rear_socket_mount_hole_d = 3.5; // mm diameter for mounting screws
rear_socket_mount_spacing = 36; // mm spacing between mounting holes

// Mid-shelf parameters (inner layer over PSU)
mid_shelf_standoff_height = 58;      // 7 cm standoffs
mid_shelf_standoff_diameter = 3;     // 3 mm standoff diameter
mid_shelf_plate_thickness = 5;       // 5 mm plate
mid_shelf_margin_from_psu = -5;       // mm distance of standoffs from PSU edges
mid_shelf_wall_clearance = 1.0;      // clearance from inner walls
mid_shelf_plate_margin_x = 25;        // plate margin around PSU in X
mid_shelf_plate_margin_y = 10;        // plate margin around PSU in Y
mid_shelf_mount_hole_d = 3.2;        // mounting hole diameter (M3 clearance)
mid_shelf_honey_border = 10;         // honeycomb border offset from plate edges (mm)

// Layout width for front-panel features (kept constant when box_width changes)
layout_width = 300;
layout_offset_x = (box_width - layout_width) / 2;
units_offset_x = 10; // offset for unit elements (multimeters and their components)

// Calculate spacing for 4 multimeters within the fixed layout width
total_multimeters_width = 4 * multimeter_width;
spacing = (layout_width - total_multimeters_width) / 5 - 3;

// Front-panel feature offsets (for consistency)
banana_offset_x = 12;   // symmetric banana jack offset from x0
banana_offset_z = 2;    // banana jack vertical offset from jack line
toggle_offset_x = -27;  // toggle switch x offset from x0
led_offset_x = 3;       // LED x offset from x0
led_offset_z = 15;      // LED vertical offset above the jack line
front_vert_offset = 3;  // global vertical lift for front units (mm)
// Banana STL alignment corrections (due to STL origin)
banana_stl_dx_left = 3;   // mm adjustment for left connector
banana_stl_dx_right = 3;  // mm adjustment for right connector
// Fuse hole under banana jacks (per unit)
fuse_hole_d = 12;        // diameter (mm)
fuse_hole_offset_z = 10; // distance below fuse hole

// 80mm fan mounting parameters
fan_hole_pitch = 71.5;       // distance between opposite screw centers (mm)
fan_mount_hole_d = 4.3;      // screw clearance diameter (mm) for M4
left_fan_center_y = box_depth - 70; // left side intake center along depth (mm)
right_fan_center_y = 70;            // right side exhaust center along depth (mm)
fan_center_z = box_height / 2;        // vertical center (mm)
fan_grill_radius = 38;              // grill radius (mm) around fan center
honeycomb_cell = 7;                 // across-flats size of hex cells (mm)
honeycomb_strut = 1.8;              // wall thickness between cells (mm)

// ---------- PARAMETRE GRUPLARI: TUREVLER/ORTAK TUREVLER ----------
// On Panel Birim Yardimcilari (ekran, banana, toggle, LED)
function unit_x_abs(i) = layout_offset_x + (spacing + i * (multimeter_width + spacing) + multimeter_width/2) + units_offset_x;
jack_line_z = (box_height*3/6 + front_vert_offset)/2;
banana_hole_center_z = jack_line_z + banana_offset_z + 5;
toggle_center_z = jack_line_z;
led_center_z = jack_line_z + led_offset_z + 5;

// Rocker ve USB/U1E merkezleri (cutout merkezleri)
rocker_center_x = box_width - layout_offset_x - 5;
rocker_center_z = box_height * 2/5 + 5;
usb_center_x = box_width - layout_offset_x - 17;
usb_center_z = box_height * 2/5 - 24;
u1e_center_x = box_width - layout_offset_x - 93;
u1e_center_z = box_height * 2/5 - 27.7;

// Arka priz merkezi (cutout merkezi)
rear_socket_center_x = 30;
rear_socket_center_z = box_height/2;

// Potansiyometre merkezleri (ekran 1'e gore)
leftmost_screen_center_x = layout_offset_x + spacing + multimeter_width/2 + units_offset_x;
pot_center_z_base = box_height*2/6 + multimeter_height/2 + front_vert_offset;
pot1_center_x = leftmost_screen_center_x - 40; // 40mm left of leftmost screen
pot2_center_x = leftmost_screen_center_x - 50; // 50mm left of leftmost screen
pot1_center_z = pot_center_z_base + pot_vertical_gap/2;
pot2_center_z = pot_center_z_base - pot_vertical_gap/2;

// STL yerlesim kalibrasyonlari (mevcut geometriyi bozmaz)
multimeter_stl_center_z = (box_height - multimeter_height*4/6) + front_vert_offset; // mevcut deger
banana_stl_y = box_depth - 3;
toggle_stl_y = box_depth - 7;
led_front_unit_stl_y = box_depth - 18;
rocker_stl_offset_x = - rocker_cutout_w / 2 + 6;
rocker_stl_offset_y = - wall_thickness + rocker_front_offset - 14;
rocker_stl_offset_z = - rocker_cutout_h / 2 + 15;

// XL4016 dizilim parametreleri (ortak kullanim)
xl4016_spacing_x = 80; // spacing between XL4016 modules
xl4016_spacing_y = 60; // spacing between XL4016 modules
xl4016_start_x = (box_width - xl4016_spacing_x) / 2 - 50; // center the grid
xl4016_start_y = (box_depth - xl4016_spacing_y) / 2 + 2;  // center the grid

// Controller karti konum ve montaj deligi parametreleri (orta raf)
controller_board_size = 100; // 10cm x 10cm controller board
controller_pos_x = box_width/2 - 57;
controller_pos_y = xl4016_start_y + xl4016_spacing_y/2 + controller_board_size / 2 + 31.5;
controller_hole_d = 3.2;       // M3 clearance
controller_hole_inset = 5;     // kenardan iceri mesafe

// Mid-shelf honeycomb keepouts (to avoid under components)
controller_keepout_margin = 8; // mm margin around controller mounting hole bounding box
// Note: controller keepout will be derived from mounting holes + margin
xl4016_keepout_w = 70;  // mm (adjust to your module)
xl4016_keepout_d = 45;  // mm (adjust to your module)

// Front Panel Layout with Cutouts
module front_panel_layout() {
    // 4 Ammeter holes
    for(i = [0:3]) {
        x_pos = spacing + i * (multimeter_width + spacing) + multimeter_width/2;
        z_pos = box_height*3/6 + front_vert_offset;
        x0 = unit_x_abs(i);
        
        // Main ammeter cutout - larger for better visibility
        translate([x0 - multimeter_width/2, -1, z_pos + 5])
        cube([multimeter_width, wall_thickness + 2, multimeter_height]);
                
        // 8mm holes for banana jacks (symmetric) below each multimeter
        // Right jack hole
        rotate([0, 0, 0])
        translate([x0 + banana_offset_x + banana_stl_dx_right, -1, banana_hole_center_z])
        rotate([-90, 0, 0])
        cylinder(h = wall_thickness + 2, r = 4, $fn=60);

        // Left jack hole (aligned to STL with banana_stl_dx_left)
        rotate([0, 0, 0])
        translate([x0 - banana_offset_x + banana_stl_dx_left, -1, banana_hole_center_z])
        rotate([-90, 0, 0])
        cylinder(h = wall_thickness + 2, r = 4, $fn=60);

        // Fuse hole 12mm (vertically aligned with LED)
        // X matches LED (x0 + led_offset_x), Z is below jack line by fuse_hole_offset_z
        rotate([0, 0, 0])
        translate([x0 + led_offset_x, -1, toggle_center_z - fuse_hole_offset_z])
        rotate([-90, 0, 0])
        cylinder(h = wall_thickness + 2, r = fuse_hole_d/2, $fn=60);

        // Toggle switch hole (12.2 mm) to the right of banana jacks
        rotate([0, 0, 0])
        translate([x0 + toggle_offset_x, -1, toggle_center_z])
        rotate([-90, 0, 0])
        cylinder(h = wall_thickness + 2, r = 12.2/2, $fn=60);
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

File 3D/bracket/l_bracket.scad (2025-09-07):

// Params (unchanged)
bracket_length = 20;
bracket_thickness = 3;
bracket_width = 10;
hole_diameter = 3.2;
hole_distance = 10;
$fn = 64;  // smoother circles

module l_bracket() {
    difference() {
        union() {
            // Vertical leg (x=thickness, y=width, z=length)
            cube([bracket_thickness, bracket_width, bracket_length]);
            // Horizontal leg (x=length, y=width, z=thickness)
            cube([bracket_length, bracket_width, bracket_thickness]);
        }

        // Hole in vertical leg: axis should be X -> rotate cylinder 90° around Y
        translate([bracket_thickness/2, bracket_width/2, hole_distance])
            rotate([0,90,0])
                cylinder(h = bracket_thickness + 2, d = hole_diameter, center = true);

        // Hole in horizontal leg: axis is Z already, so no rotate needed
        translate([hole_distance, bracket_width/2, bracket_thickness/2])
            cylinder(h = bracket_thickness + 2, d = hole_diameter, center = true);
    }
}

l_bracket();

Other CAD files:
3D/exports/left.stl
3D/fuse/KLS5-258 (FH-B02), Fuse holder 5,2х20.stl
3D/led/TC-R9-107 5mm v3.stl
3D/pot/Bourns 3590S-291-103L.step
3D/socket/AC 3-Pin With Fuse.stp
3D/tri_corner/corner bracket v1.scad
3D/exports/back.stl
3D/exports/bottom.stl
3D/exports/front.stl
3D/exports/mid.stl
3D/exports/top.stl
3D/multimeter/v & a metr.SLDPRT
3D/multimeter/v & a metr.stl
3D/multimeter/v & a metr.x_t
3D/pot/Knob.step
3D/socket/Soket.STEP
3D/switch/SPDT_Toggle_Switch.stl
3D/switch/Tekli-Montaj_Shrinkwrap_1.stl
3D/tri_corner/triangle_corner.scad
3D/usb/Dual USB A charger fini v004.stl
Protection/generated/3d/Protection_board.step
Protection/generated/3d/Protection_board.stl

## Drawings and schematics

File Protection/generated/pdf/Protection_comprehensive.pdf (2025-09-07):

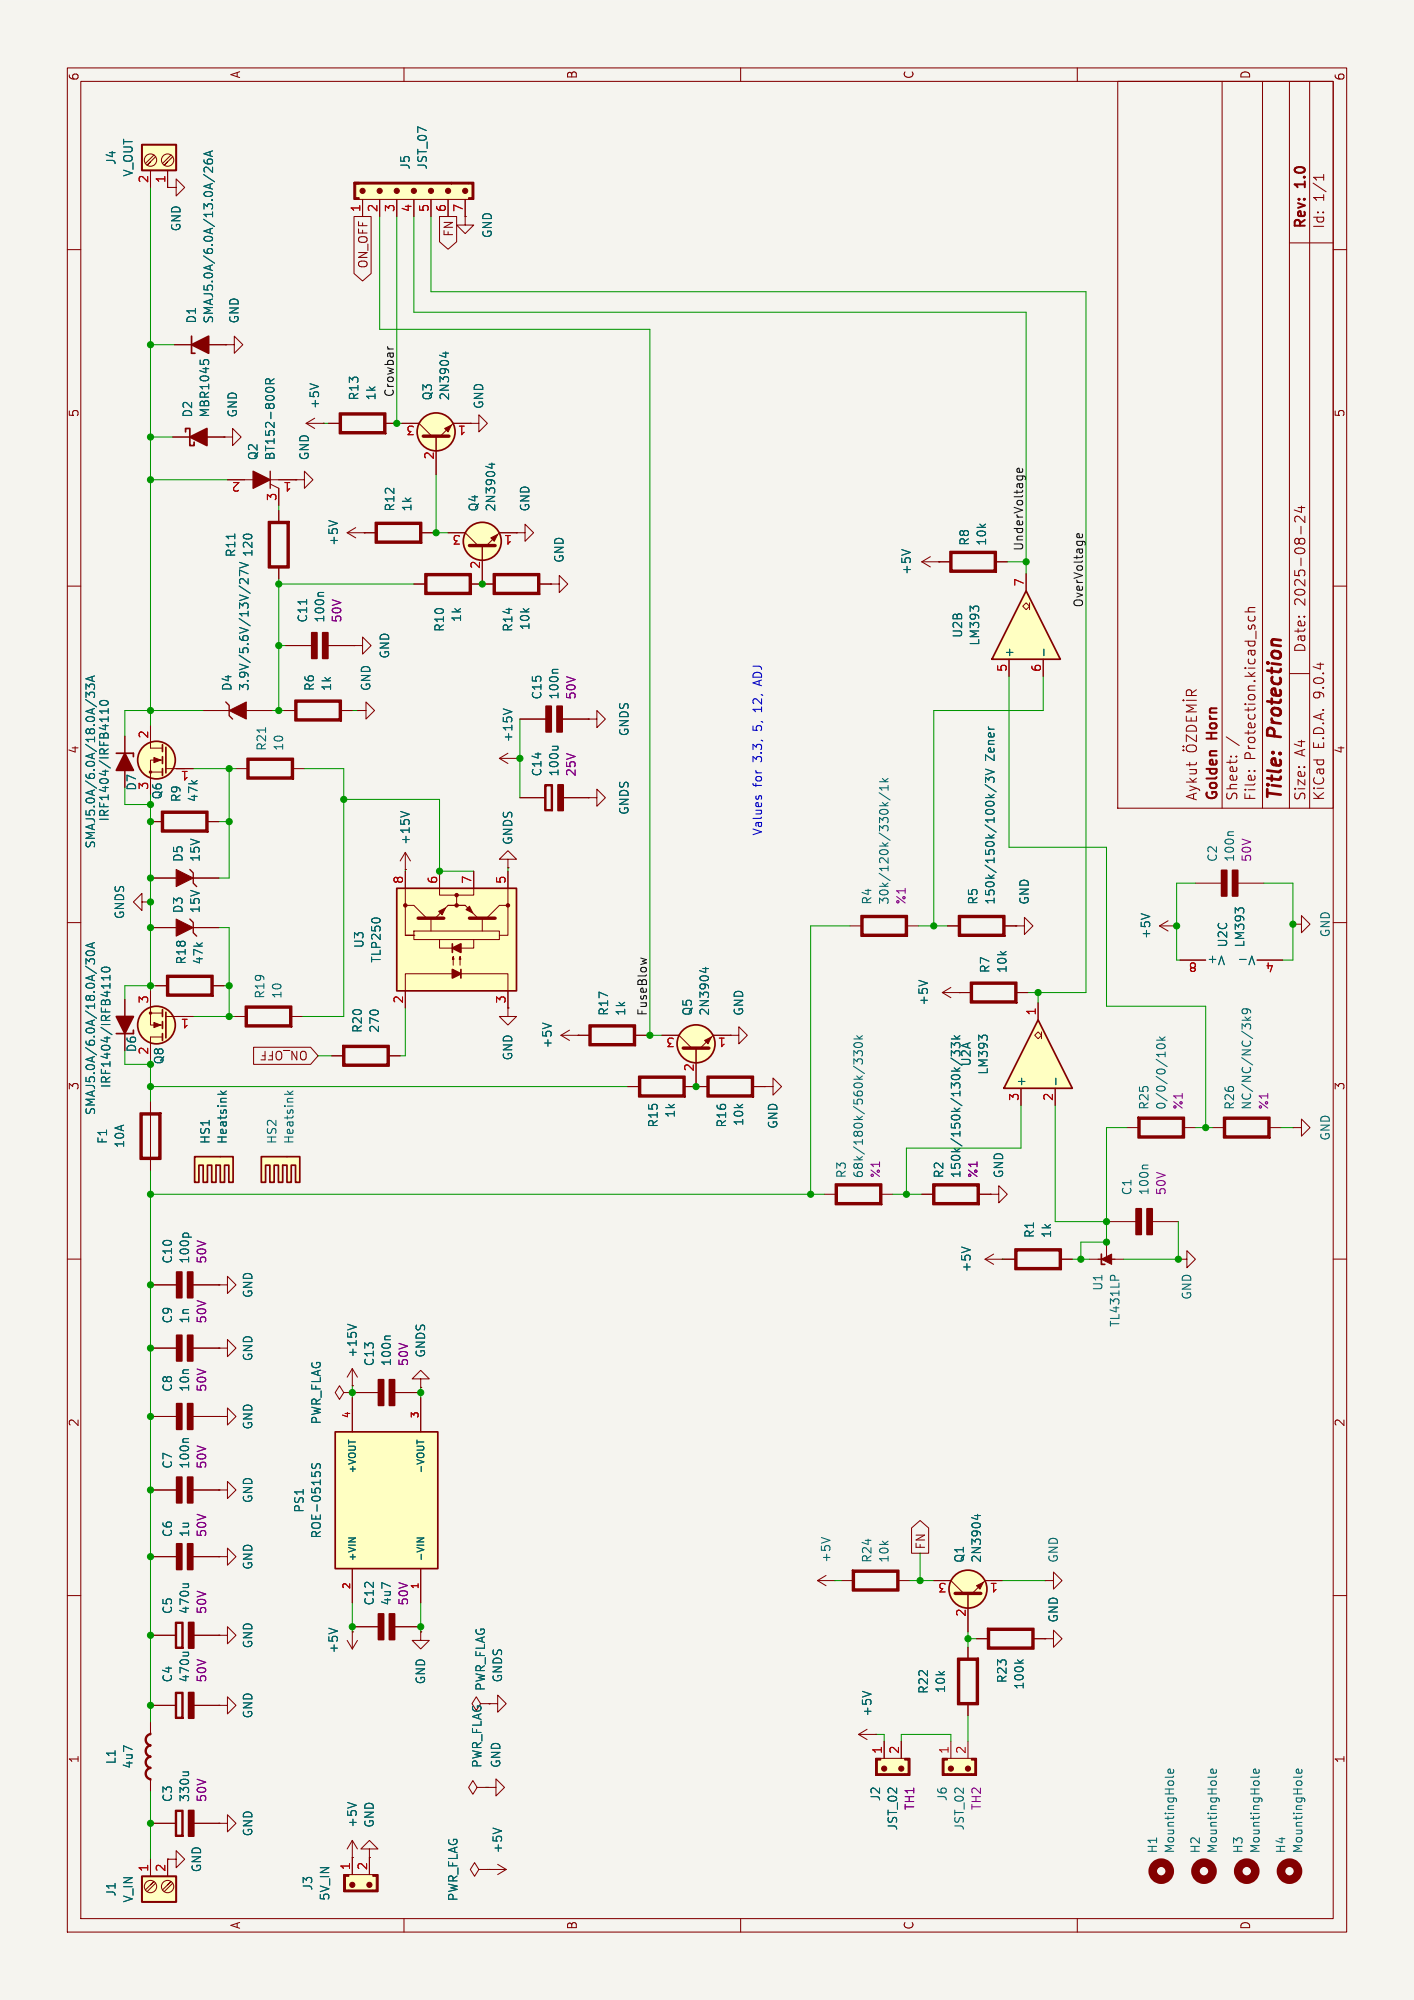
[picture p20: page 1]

GND GND

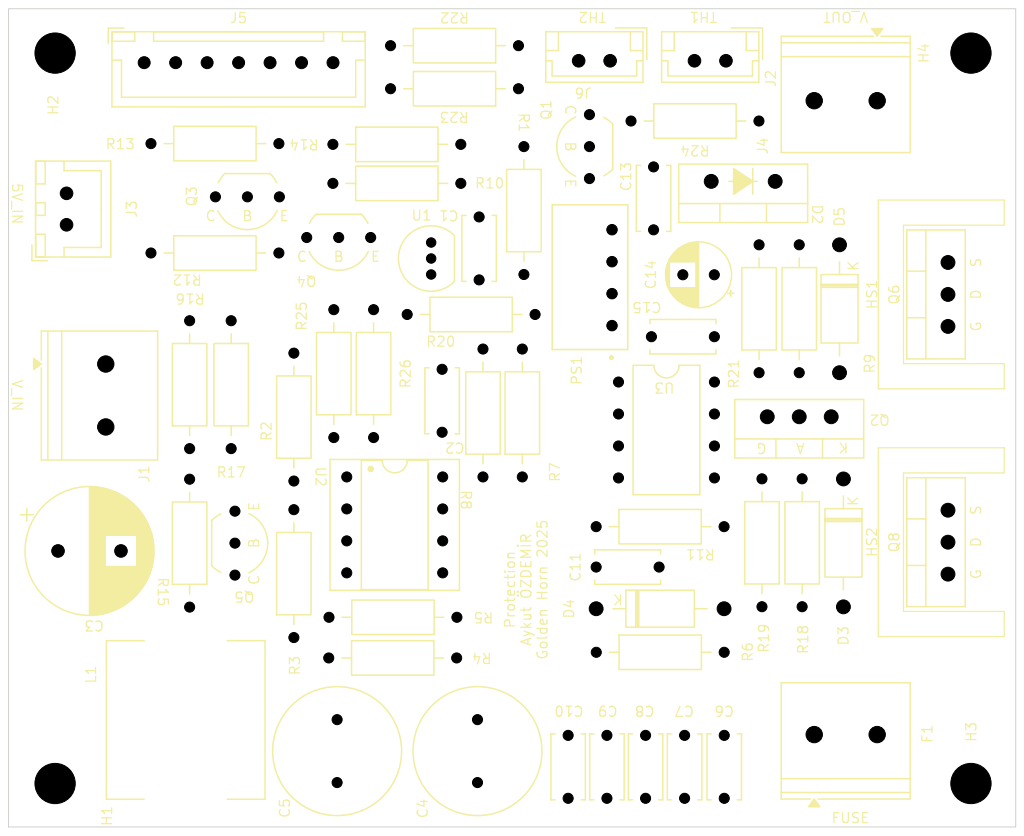
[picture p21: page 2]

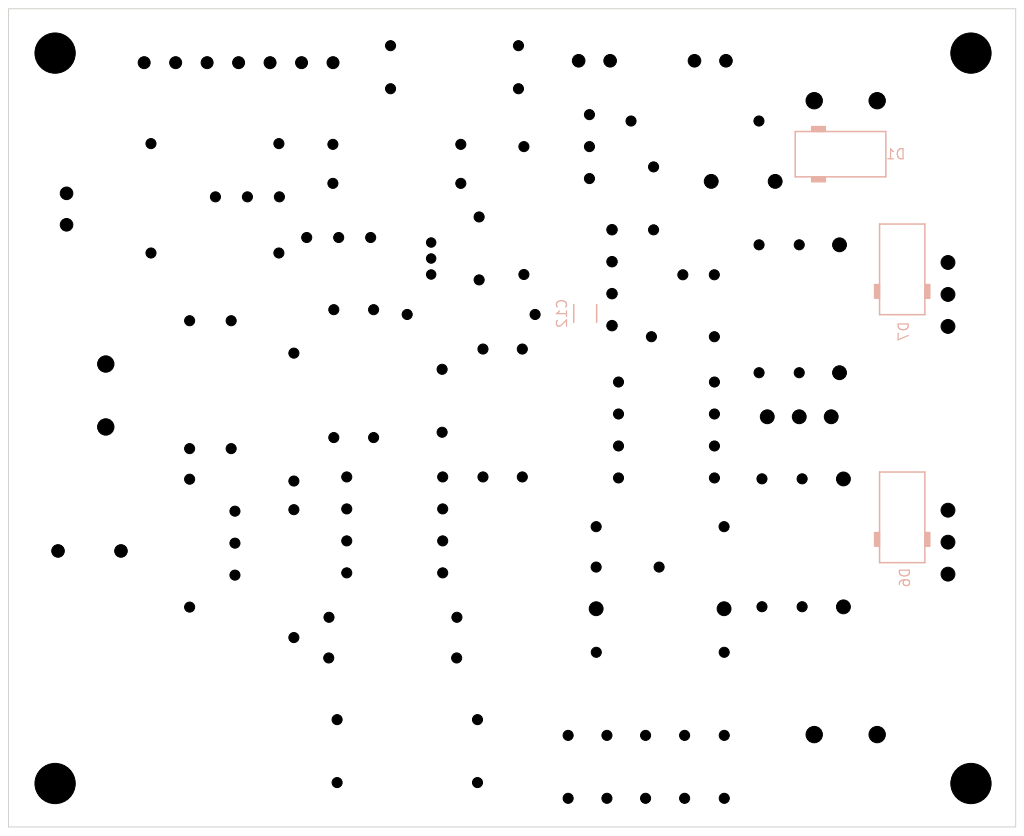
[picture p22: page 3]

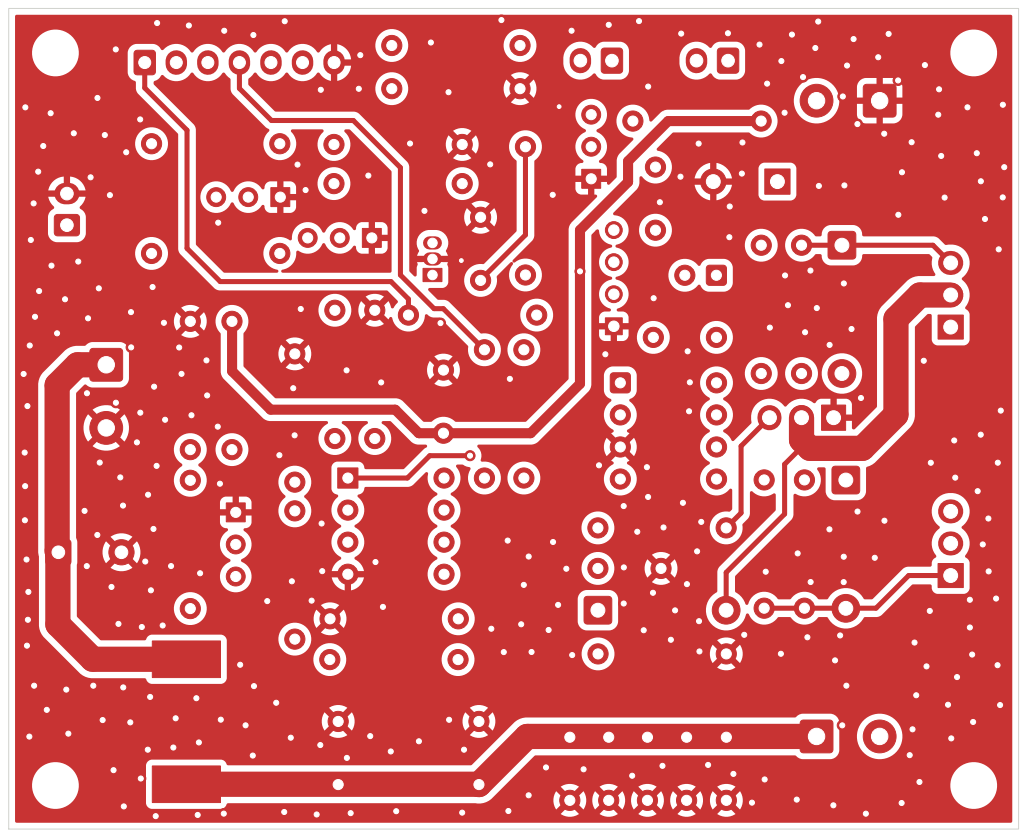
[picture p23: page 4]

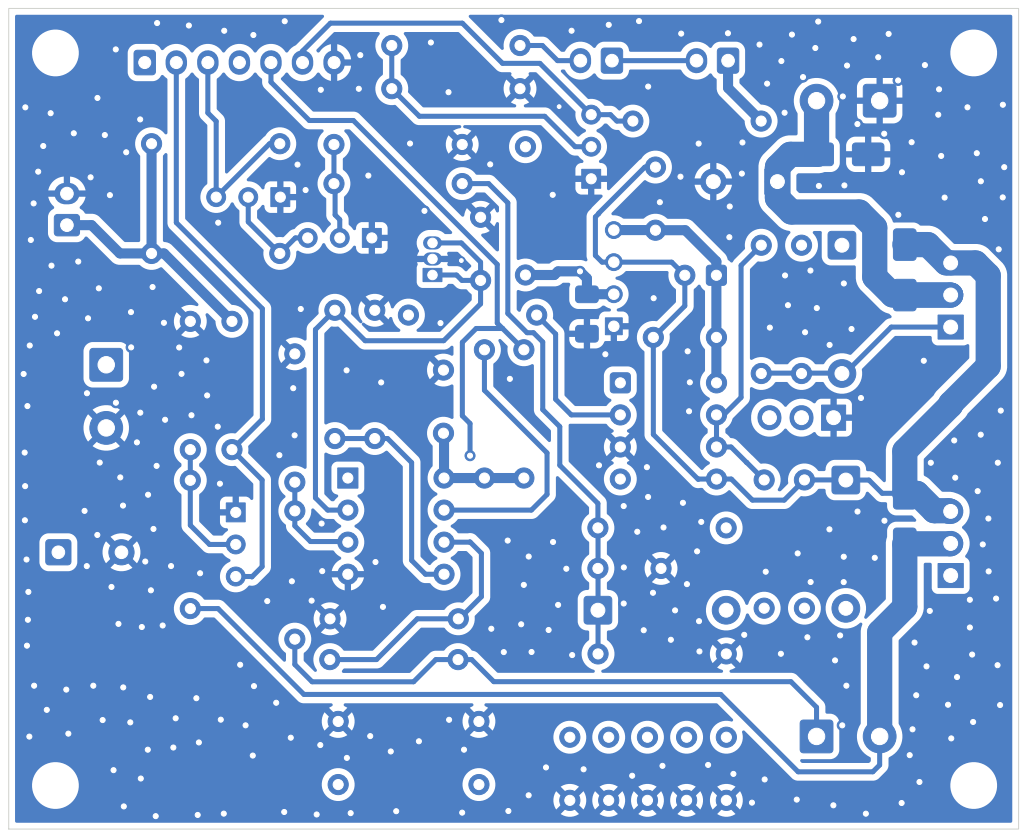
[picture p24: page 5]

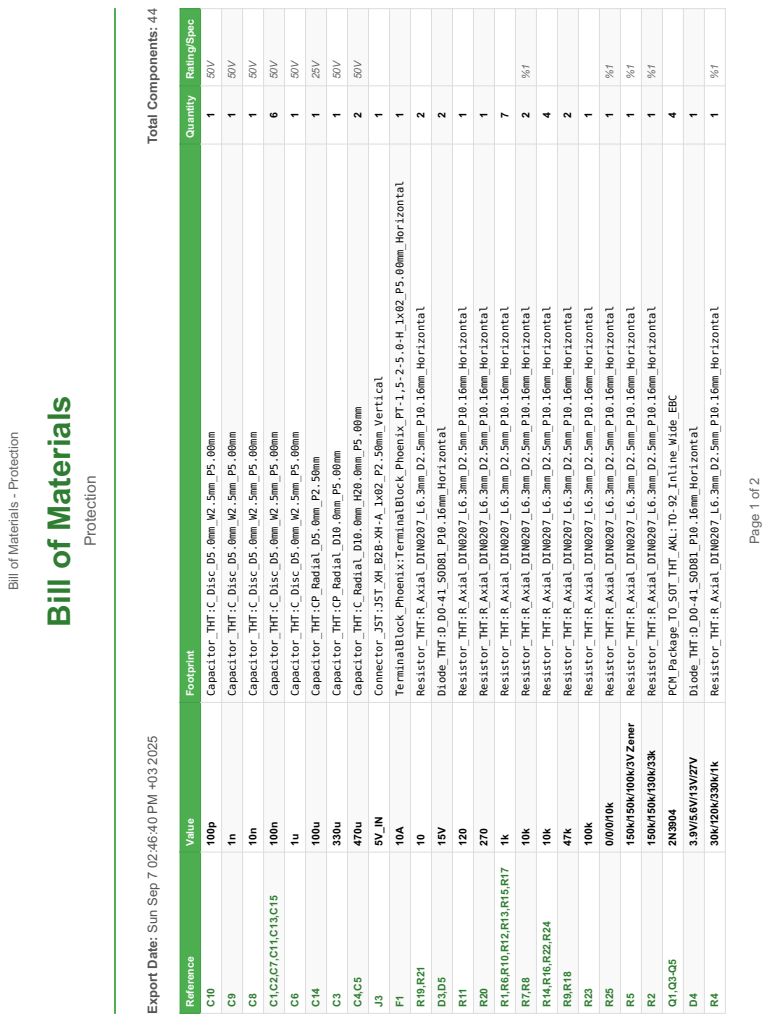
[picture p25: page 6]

Export Date: Sun Sep 7 02:46:40 PM +03 2025 Total Components: 44

Reference Value Footprint Quantity Rating/Spec

Bill of Materials - Protection

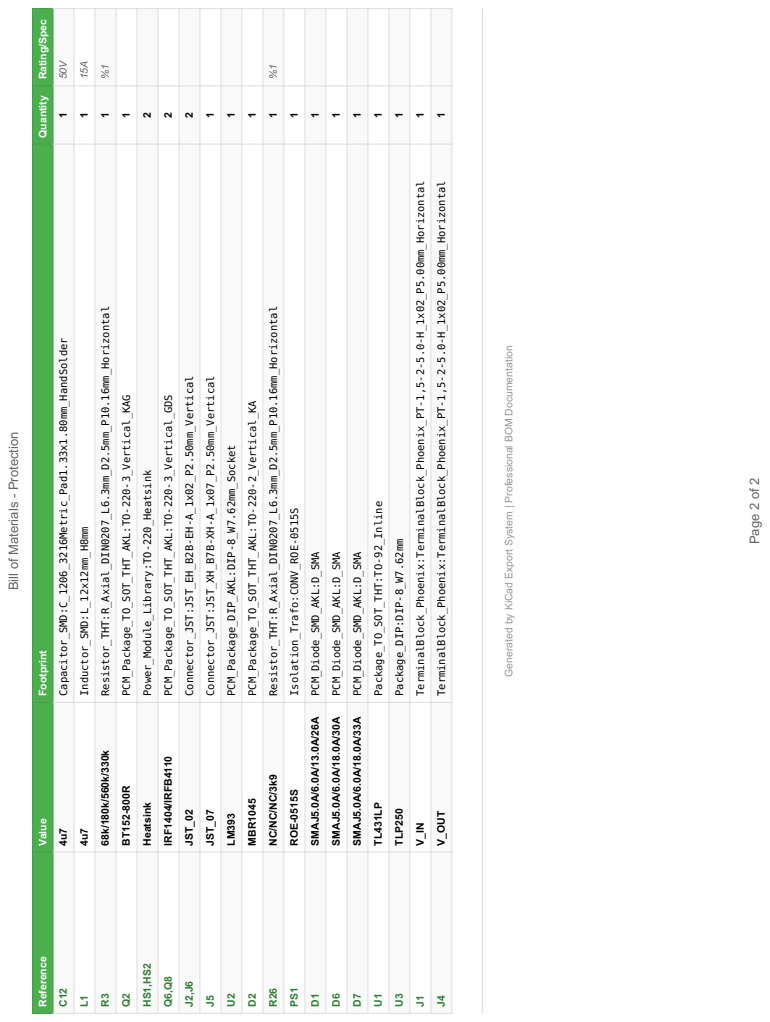
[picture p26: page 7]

Reference Value Footprint Quantity Rating/Spec

Generated by KiCad Export System | Professional BOM Documentation

Bill of Materials - Protection

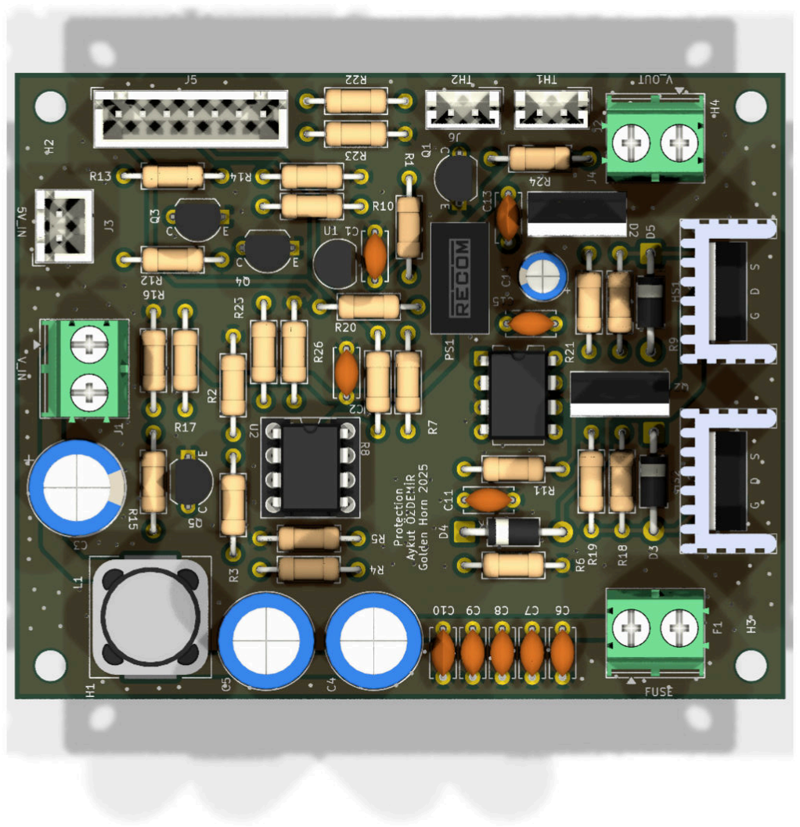
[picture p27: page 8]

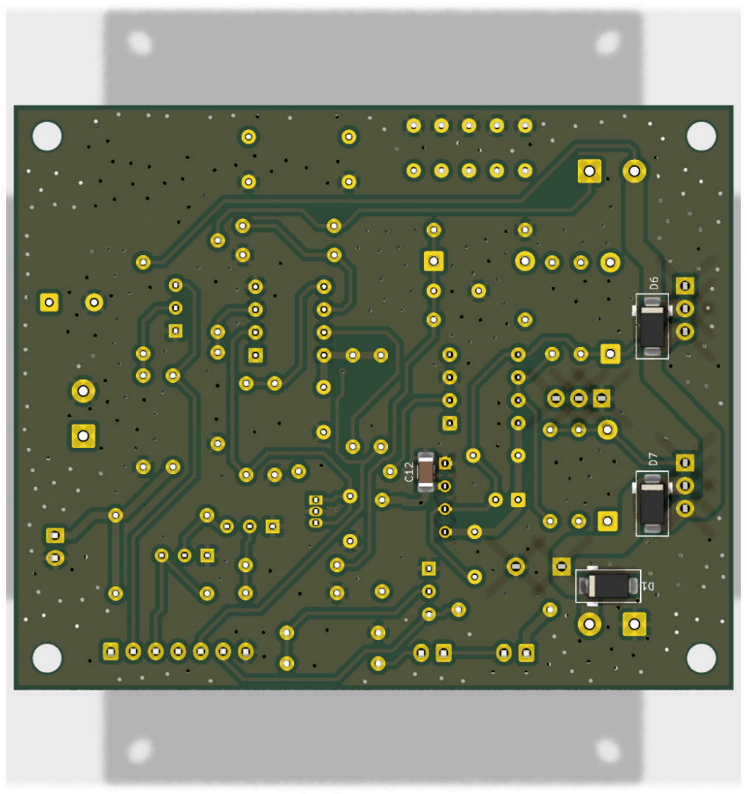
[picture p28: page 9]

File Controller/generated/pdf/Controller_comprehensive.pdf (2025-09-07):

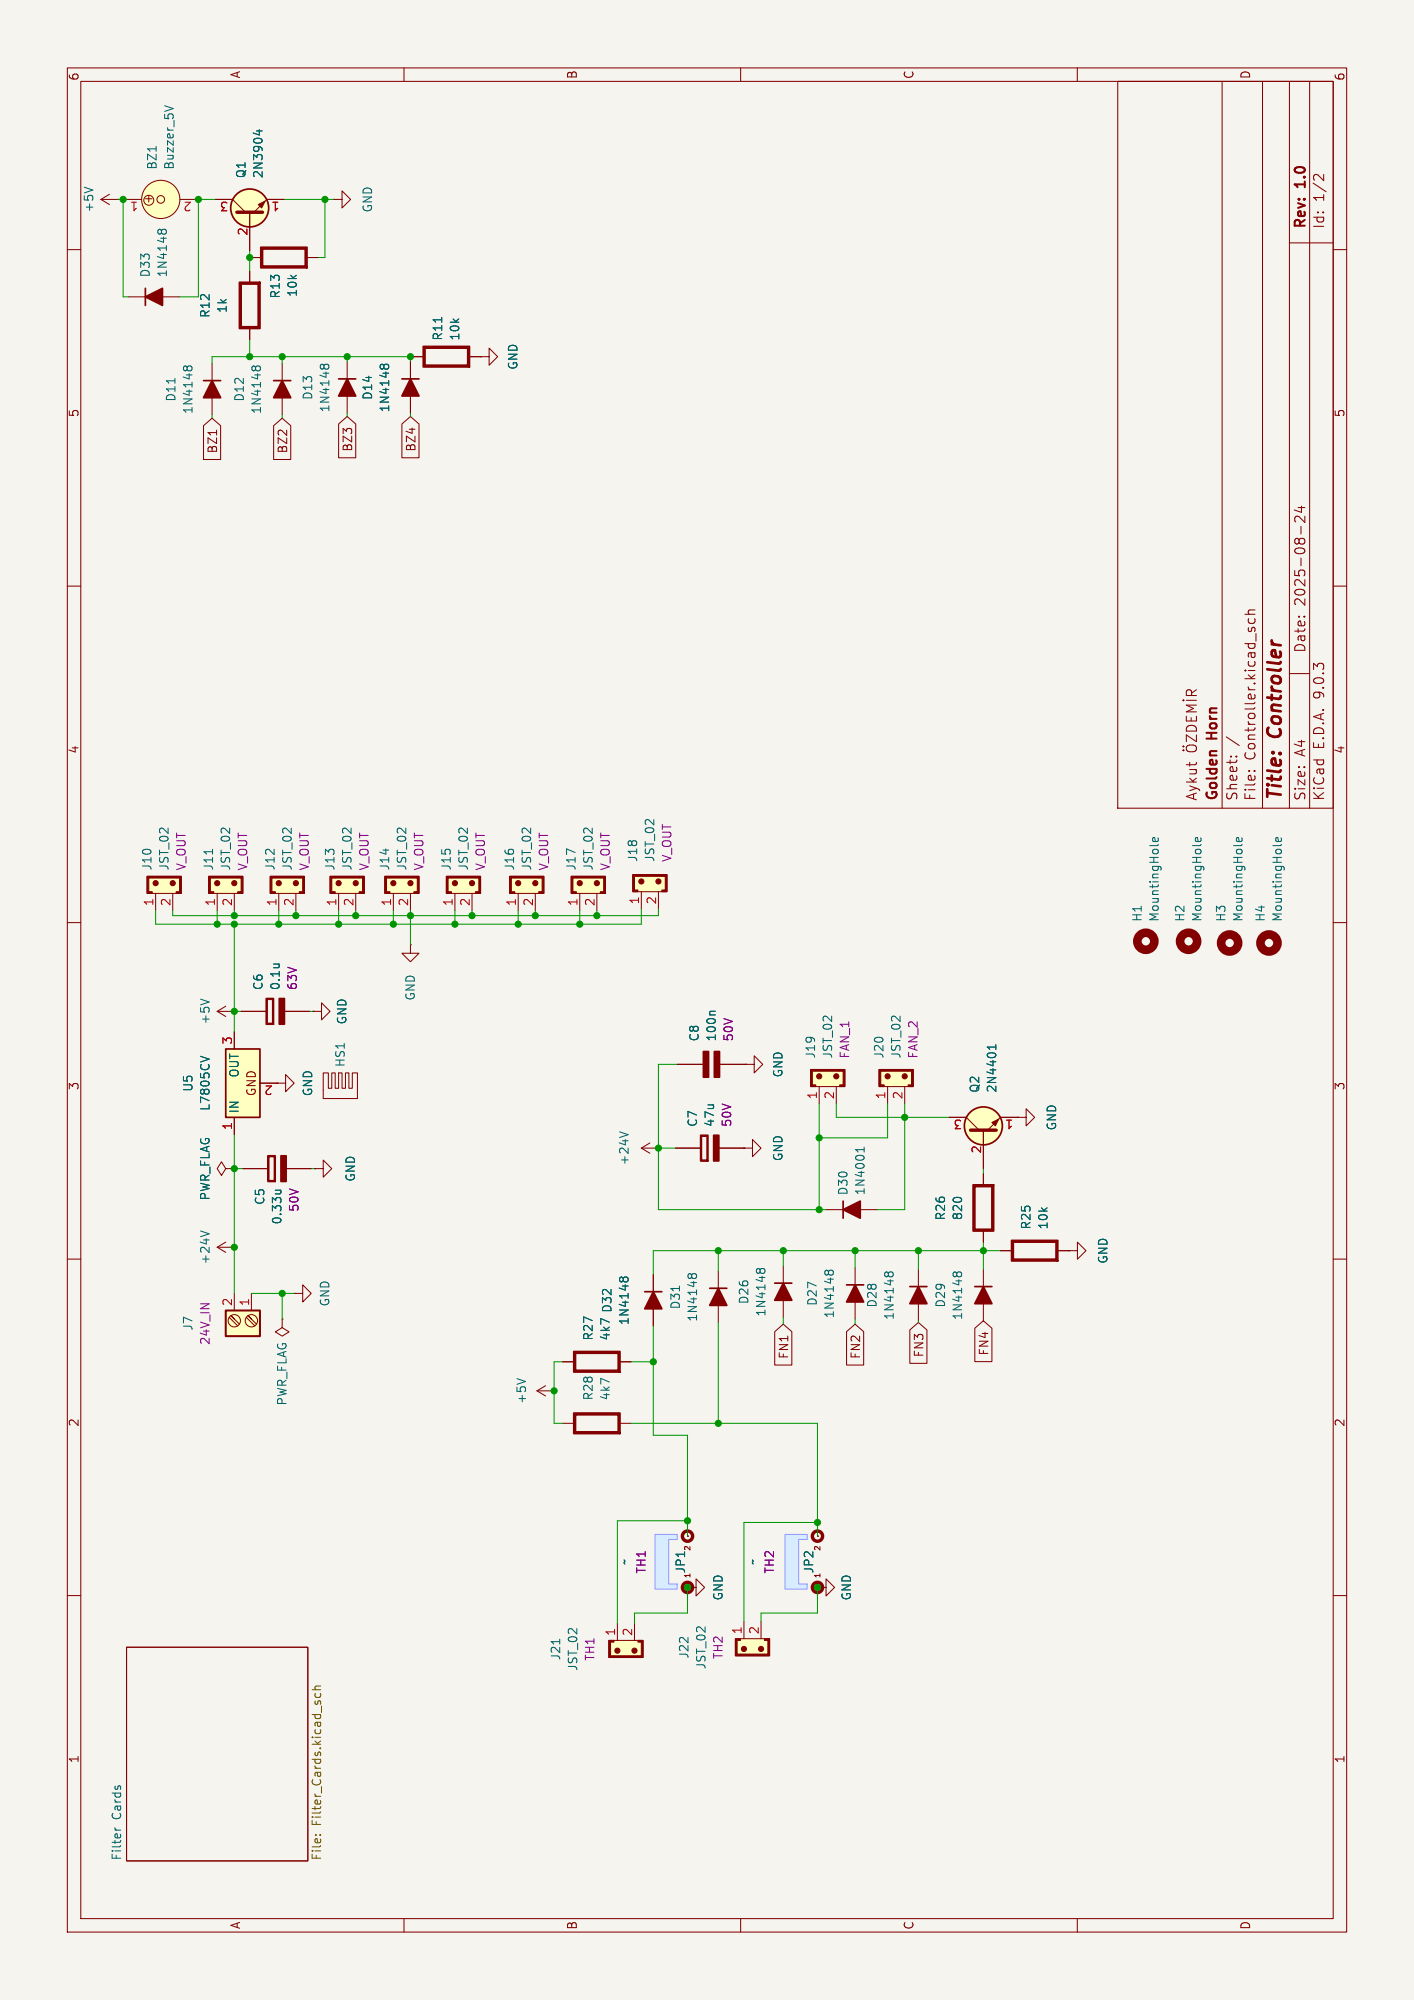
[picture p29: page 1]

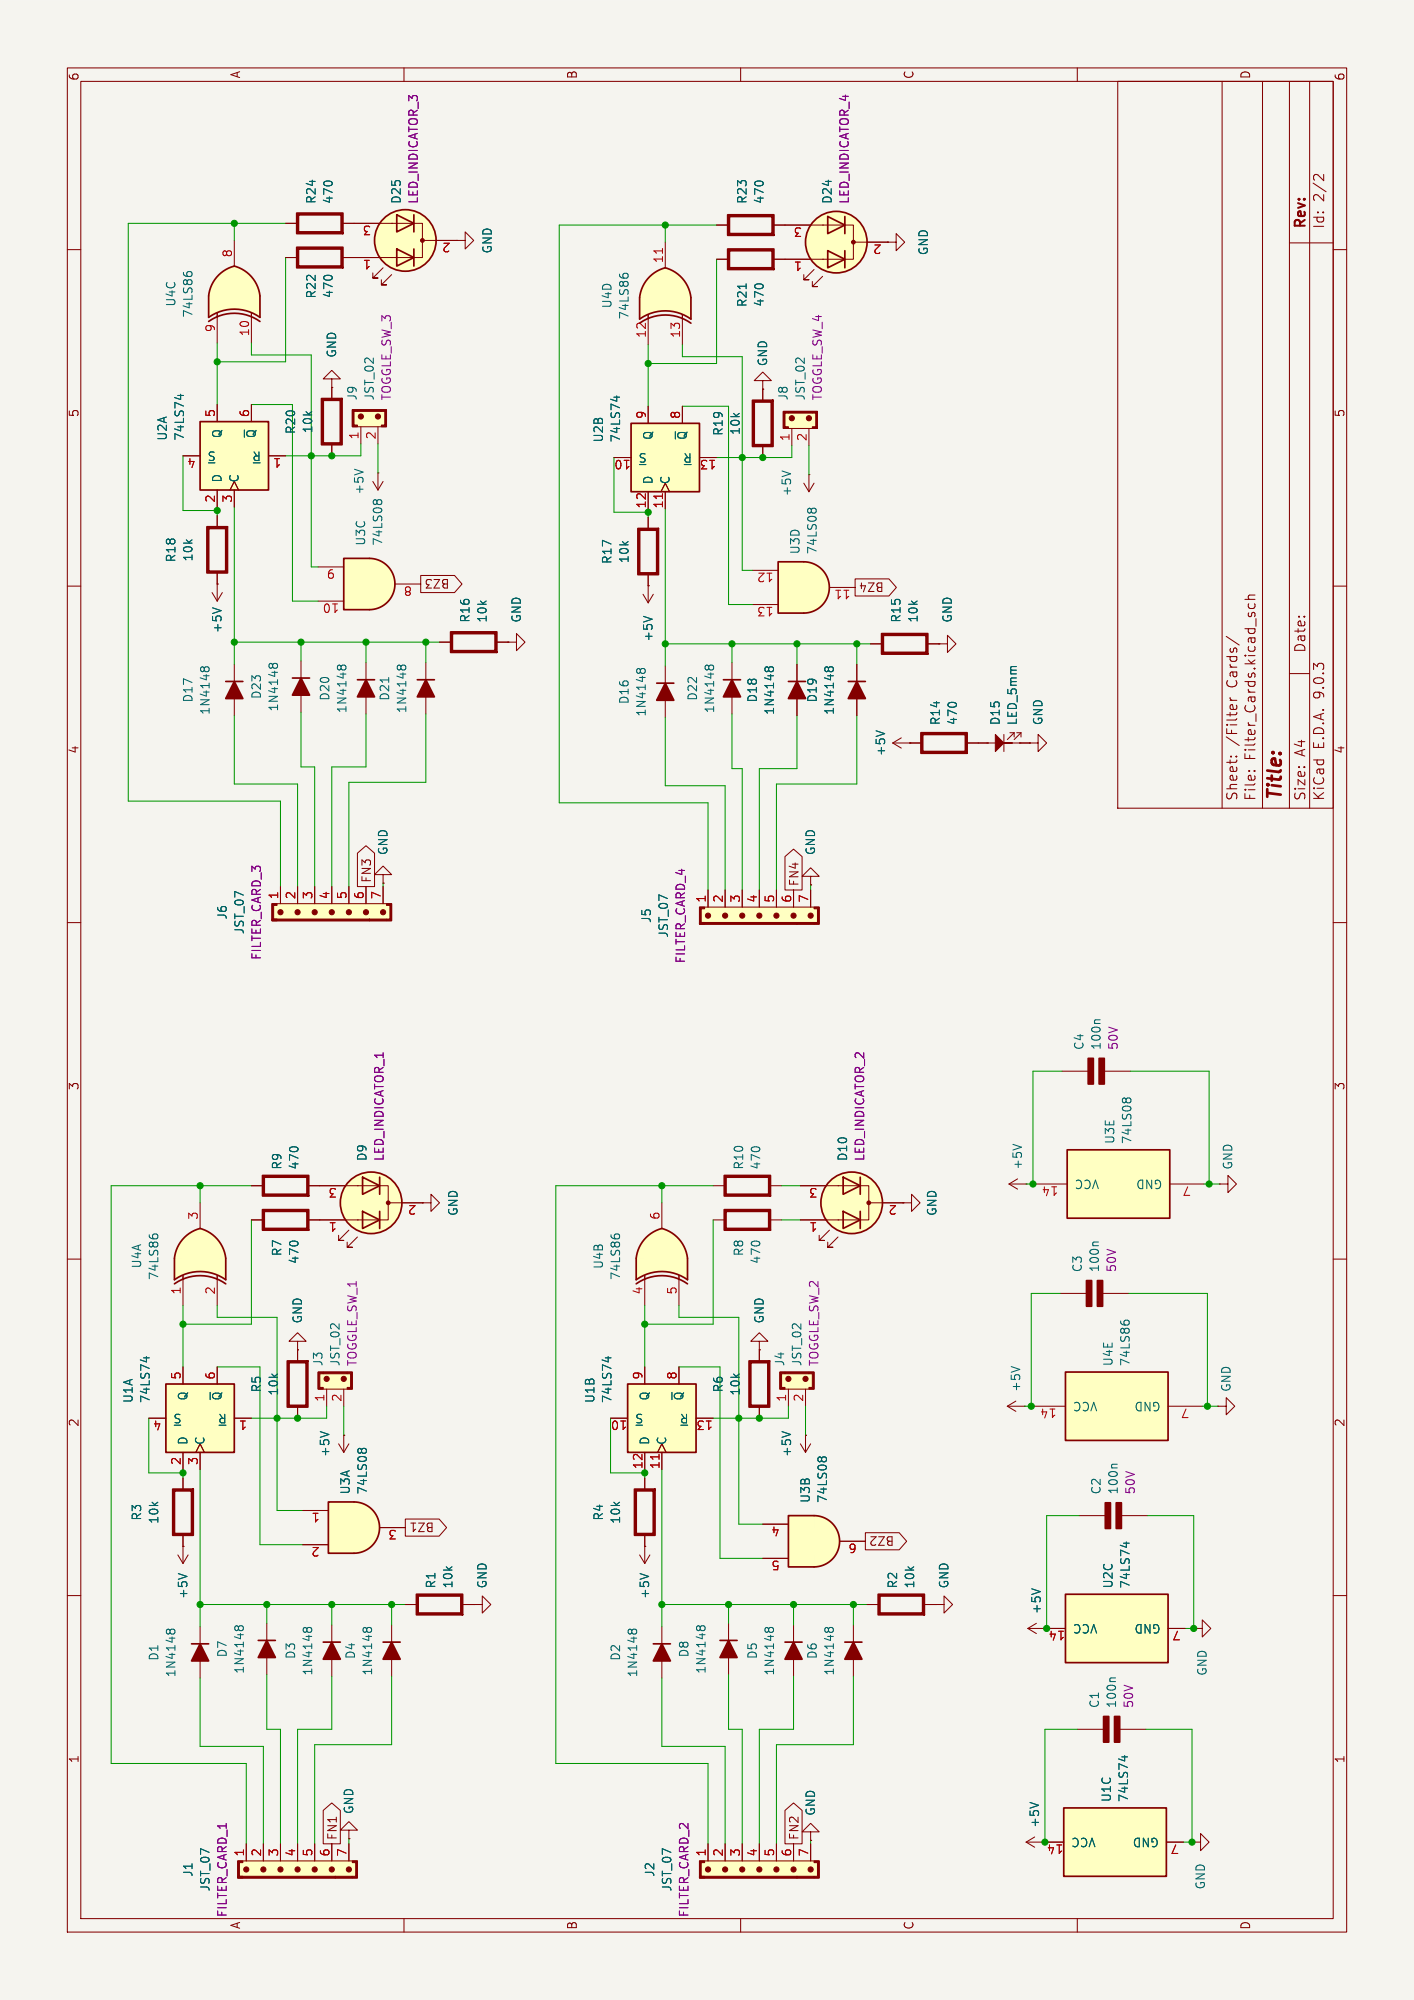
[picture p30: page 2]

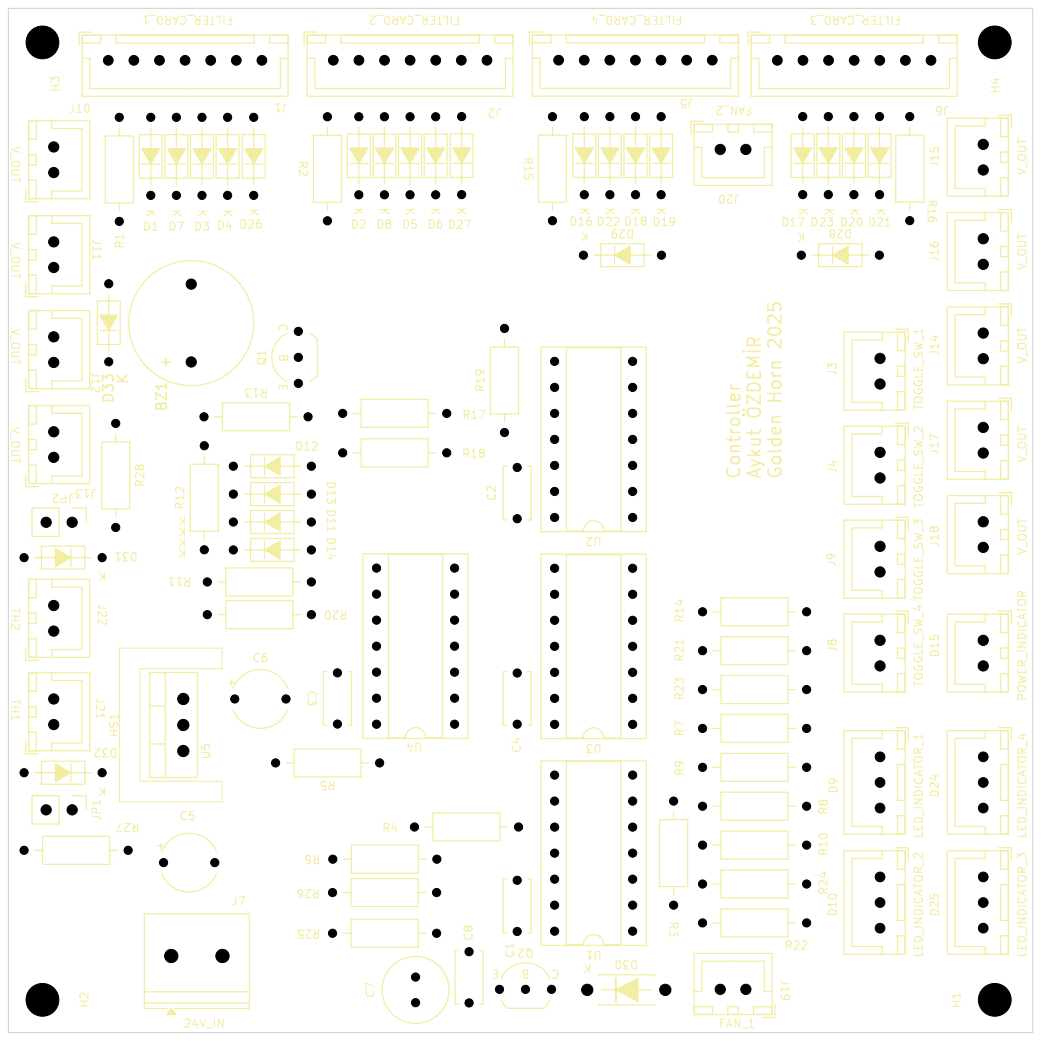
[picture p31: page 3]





Export Date: Wed Aug 27 04:48:46 PM +03 2025 Total Components: 26

Reference Value Footprint Quantity Rating/ Spec

Bill of Materials - Controller


Reference Value Footprint Quantity Rating/ Spec

Generated by KiCad Export System | Professional BOM Documentation

Bill of Materials - Controller












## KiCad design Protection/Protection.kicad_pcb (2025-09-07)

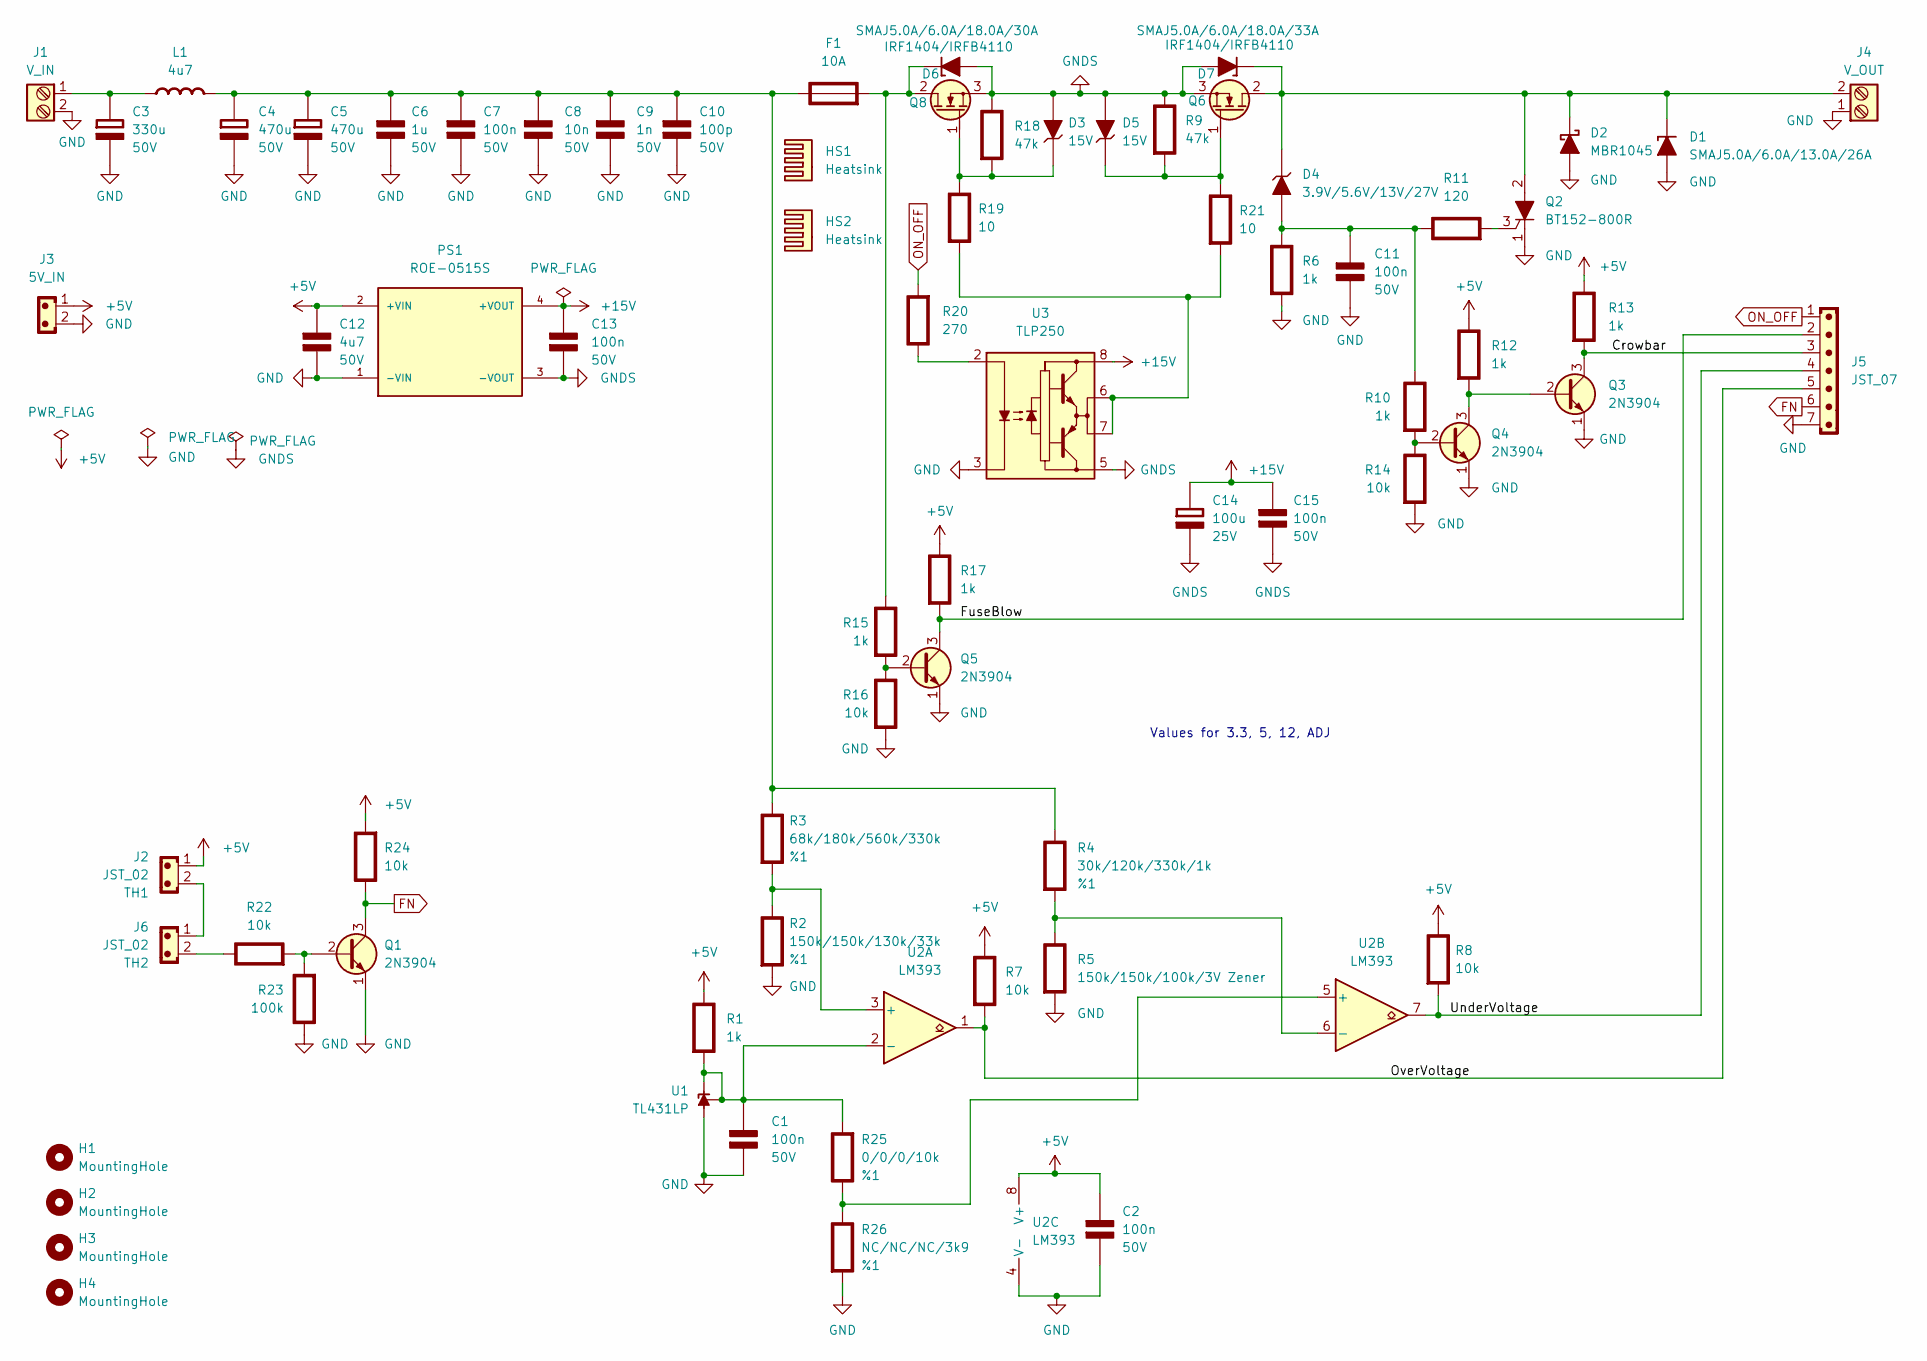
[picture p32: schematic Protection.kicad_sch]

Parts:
C1, C2, C7, C11, C13, C15: 100n; C_Disc_D5.0mm_W2.5mm_P5.00mm; Rating 50V
C3: 330u; CP_Radial_D10.0mm_P5.00mm; Rating 50V
C4, C5: 470u; C_Radial_D10.0mm_H20.0mm_P5.00mm; Rating 50V
C6: 1u; C_Disc_D5.0mm_W2.5mm_P5.00mm; Rating 50V
C8: 10n; C_Disc_D5.0mm_W2.5mm_P5.00mm; Rating 50V
C9: 1n; C_Disc_D5.0mm_W2.5mm_P5.00mm; Rating 50V
C10: 100p; C_Disc_D5.0mm_W2.5mm_P5.00mm; Rating 50V
C12: 4u7; C_1206_3216Metric_Pad1.33x1.80mm_HandSolder; Rating 50V
C14: 100u; CP_Radial_D5.0mm_P2.50mm; Rating 25V
D1: SMAJ5.0A/6.0A/13.0A/26A; D_SMA
D2: MBR1045; TO-220-2_Vertical_KA
D3, D5: 15V; D_DO-41_SOD81_P10.16mm_Horizontal
D4: 3.9V/5.6V/13V/27V; D_DO-41_SOD81_P10.16mm_Horizontal
D6: SMAJ5.0A/6.0A/18.0A/30A; D_SMA
D7: SMAJ5.0A/6.0A/18.0A/33A; D_SMA
F1: 10A; TerminalBlock_Phoenix_PT-1,5-2-5.0-H_1x02_P5.00mm_Horizontal
H1, H2, H3, H4: MountingHole; MountingHole_3.2mm_M3_DIN965
HS1, HS2: Heatsink; TO-220_Heatsink
J1: V_IN; TerminalBlock_Phoenix_PT-1,5-2-5.0-H_1x02_P5.00mm_Horizontal
J2, J6: JST_02; JST_EH_B2B-EH-A_1x02_P2.50mm_Vertical
J3: 5V_IN; JST_XH_B2B-XH-A_1x02_P2.50mm_Vertical
J4: V_OUT; TerminalBlock_Phoenix_PT-1,5-2-5.0-H_1x02_P5.00mm_Horizontal
J5: JST_07; JST_XH_B7B-XH-A_1x07_P2.50mm_Vertical
L1: 4u7; L_12x12mm_H8mm; Rating 15A
PS1: ROE-0515S; CONV_ROE-0515S; PARTREV 5
Q1, Q3, Q4, Q5: 2N3904; TO-92_Inline_Wide_EBC
Q2: BT152-800R; TO-220-3_Vertical_KAG
Q6, Q8: IRF1404/IRFB4110; TO-220-3_Vertical_GDS
R1, R6, R10, R12, R13, R15, R17: 1k; R_Axial_DIN0207_L6.3mm_D2.5mm_P10.16mm_Horizontal
R2: 150k/150k/130k/33k; R_Axial_DIN0207_L6.3mm_D2.5mm_P10.16mm_Horizontal; Rating %1
R3: 68k/180k/560k/330k; R_Axial_DIN0207_L6.3mm_D2.5mm_P10.16mm_Horizontal; Rating %1
R4: 30k/120k/330k/1k; R_Axial_DIN0207_L6.3mm_D2.5mm_P10.16mm_Horizontal; Rating %1
R5: 150k/150k/100k/3V Zener; R_Axial_DIN0207_L6.3mm_D2.5mm_P10.16mm_Horizontal; Rating %1
R7, R8: 10k; R_Axial_DIN0207_L6.3mm_D2.5mm_P10.16mm_Horizontal; Rating %1
R9, R18: 47k; R_Axial_DIN0207_L6.3mm_D2.5mm_P10.16mm_Horizontal
R11: 120; R_Axial_DIN0207_L6.3mm_D2.5mm_P10.16mm_Horizontal
R14, R16, R22, R24: 10k; R_Axial_DIN0207_L6.3mm_D2.5mm_P10.16mm_Horizontal
R19, R21: 10; R_Axial_DIN0207_L6.3mm_D2.5mm_P10.16mm_Horizontal
R20: 270; R_Axial_DIN0207_L6.3mm_D2.5mm_P10.16mm_Horizontal
R23: 100k; R_Axial_DIN0207_L6.3mm_D2.5mm_P10.16mm_Horizontal
R25: 0/0/0/10k; R_Axial_DIN0207_L6.3mm_D2.5mm_P10.16mm_Horizontal; Rating %1
R26: NC/NC/NC/3k9; R_Axial_DIN0207_L6.3mm_D2.5mm_P10.16mm_Horizontal; Rating %1
U1: TL431LP; TO-92_Inline
U2: LM393; DIP-8_W7.62mm_Socket
U3: TLP250; DIP-8_W7.62mm

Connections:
+5V: C2.1 (+), C12.1 (+), J2.1, J3.1, PS1.2 (+VIN), R1.1 (+), R7.1 (+), R8.1 (+), R12.1 (+), R13.1 (+), R17.1 (+), R24.2 (-), U2.8 (V+)
+15V: C13.1 (+), C14.1 (+), C15.1 (+), PS1.4 (+VOUT), U3.8 (VCC)
/Crowbar: J5.3, Q3.3 (C), R13.2 (-)
/FuseBlow: J5.2, Q5.3 (C), R17.2 (-)
/OverVoltage: J5.5, R7.2 (-), U2.1
/UnderVoltage: J5.4, R8.2 (-), U2.7
FN: J5.6, Q1.3 (C), R24.1 (+)
GND: C1.2 (-), C2.2 (-), C3.2 (-), C4.2 (-), C5.2 (-), C6.2 (-), C7.2 (-), C8.2 (-), C9.2 (-), C10.2 (-), C11.2 (-), C12.2 (-), D1.2 (A), D2.2 (A), J1.2, J3.2, J4.1, J5.7, PS1.1 (-VIN), Q1.1 (E), Q2.1 (K), Q3.1 (E), Q4.1 (E), Q5.1 (E), R2.2 (-), R5.2 (-), R6.2 (-), R14.2 (-), R16.2 (-), R23.1 (+), R26.2 (-), U1.2 (A), U2.4 (V-), U3.3 (C)
GNDS: C13.2 (-), C14.2 (-), C15.2 (-), D3.1 (A), D5.1 (A), D6.2 (A), D7.2 (A), PS1.3 (-VOUT), Q6.3 (S), Q8.3 (S), R9.1 (+), R18.1 (+), U3.5 (VEE)
unnamed: C1.1 (+), R1.2 (-), R25.2 (-), U1.1 (REF), U1.3 (K), U2.2 (-)
unnamed: C3.1 (+), J1.1, L1.1 (+)
unnamed: C4.1 (+), C5.1 (+), C6.1 (+), C7.1 (+), C8.1 (+), C9.1 (+), C10.1 (+), F1.1 (+), L1.2 (-), R3.1 (+), R4.1 (+)
unnamed: C11.1 (+), D4.1 (A), R6.1 (+), R10.1 (+), R11.1 (+)
unnamed: D1.1 (K), D2.1 (K), D4.2 (K), D7.1 (K), J4.2, Q2.2 (A), Q6.2 (D)
unnamed: D3.2 (K), Q8.1 (G), R18.2 (-), R19.1 (+)
unnamed: D5.2 (K), Q6.1 (G), R9.2 (-), R21.1 (+)
unnamed: D6.1 (K), F1.2 (-), Q8.2 (D), R15.1 (+)
unnamed: J2.2, J6.1
unnamed: Q1.2 (B), R22.2 (-), R23.2 (-)
unnamed: Q2.3 (G), R11.2 (-)
unnamed: Q3.2 (B), Q4.3 (C), R12.2 (-)
unnamed: Q4.2 (B), R10.2 (-), R14.1 (+)
unnamed: Q5.2 (B), R15.2 (-), R16.1 (+)
unnamed: R2.1 (+), R3.2 (-), U2.3 (+)
unnamed: R4.2 (-), R5.1 (+), U2.6 (-)
unnamed: R19.2 (-), R21.2 (-), U3.6 (VO), U3.7 (VO)
unnamed: R20.1 (+), U3.2 (A)
unnamed: J6.2, R22.1 (+)
unnamed: R25.1 (+), R26.1 (+), U2.5 (+)
ON_OFF: J5.1, R20.2 (-)

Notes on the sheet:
Values for 3.3, 5, 12, ADJ

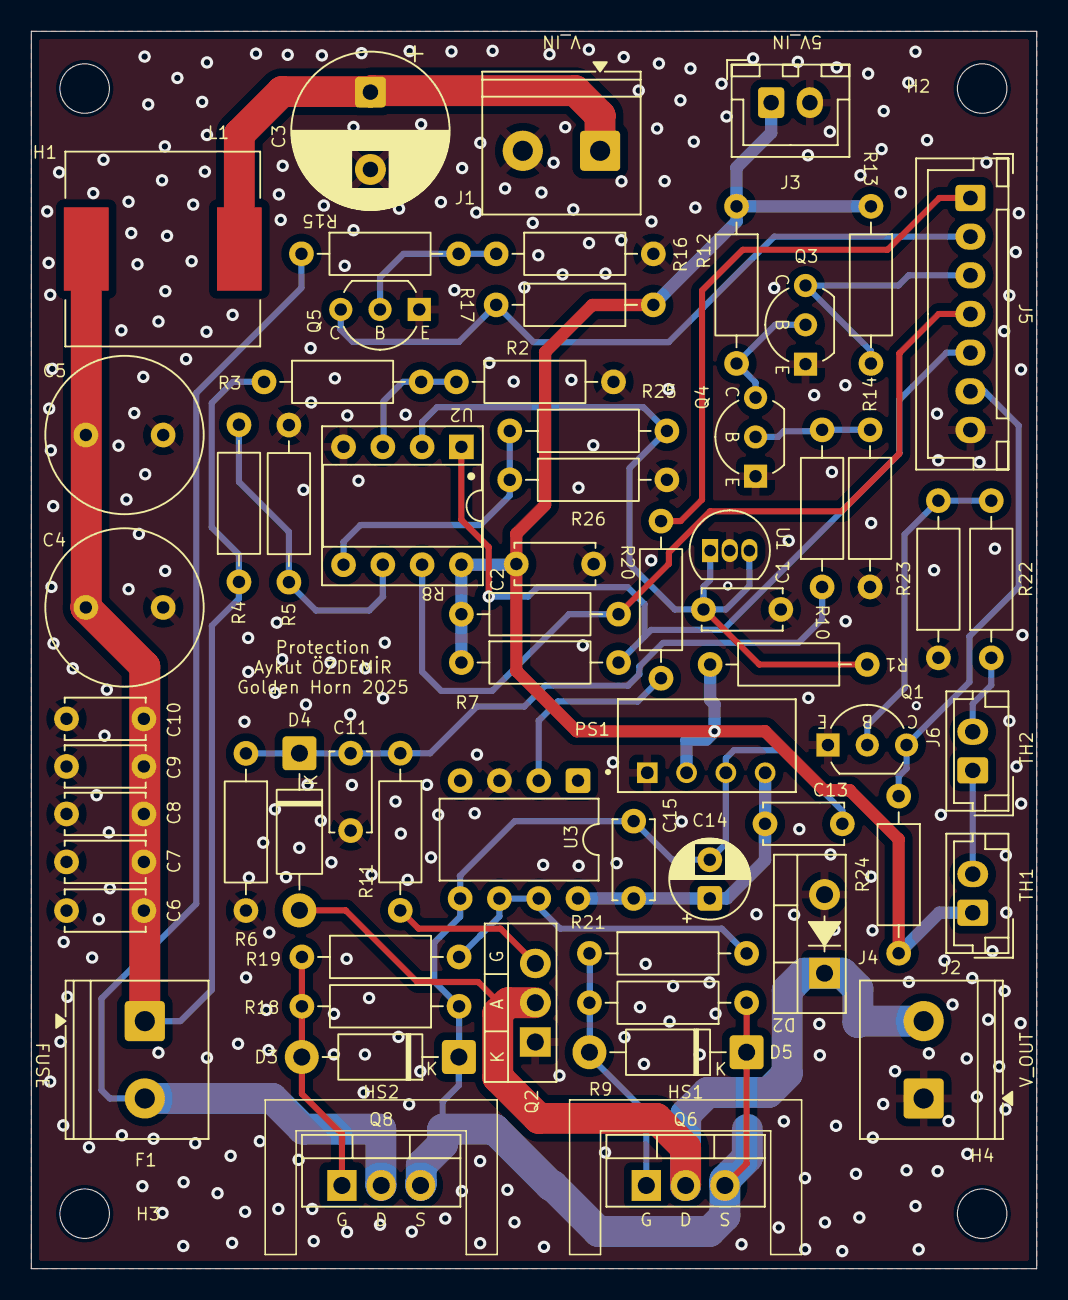
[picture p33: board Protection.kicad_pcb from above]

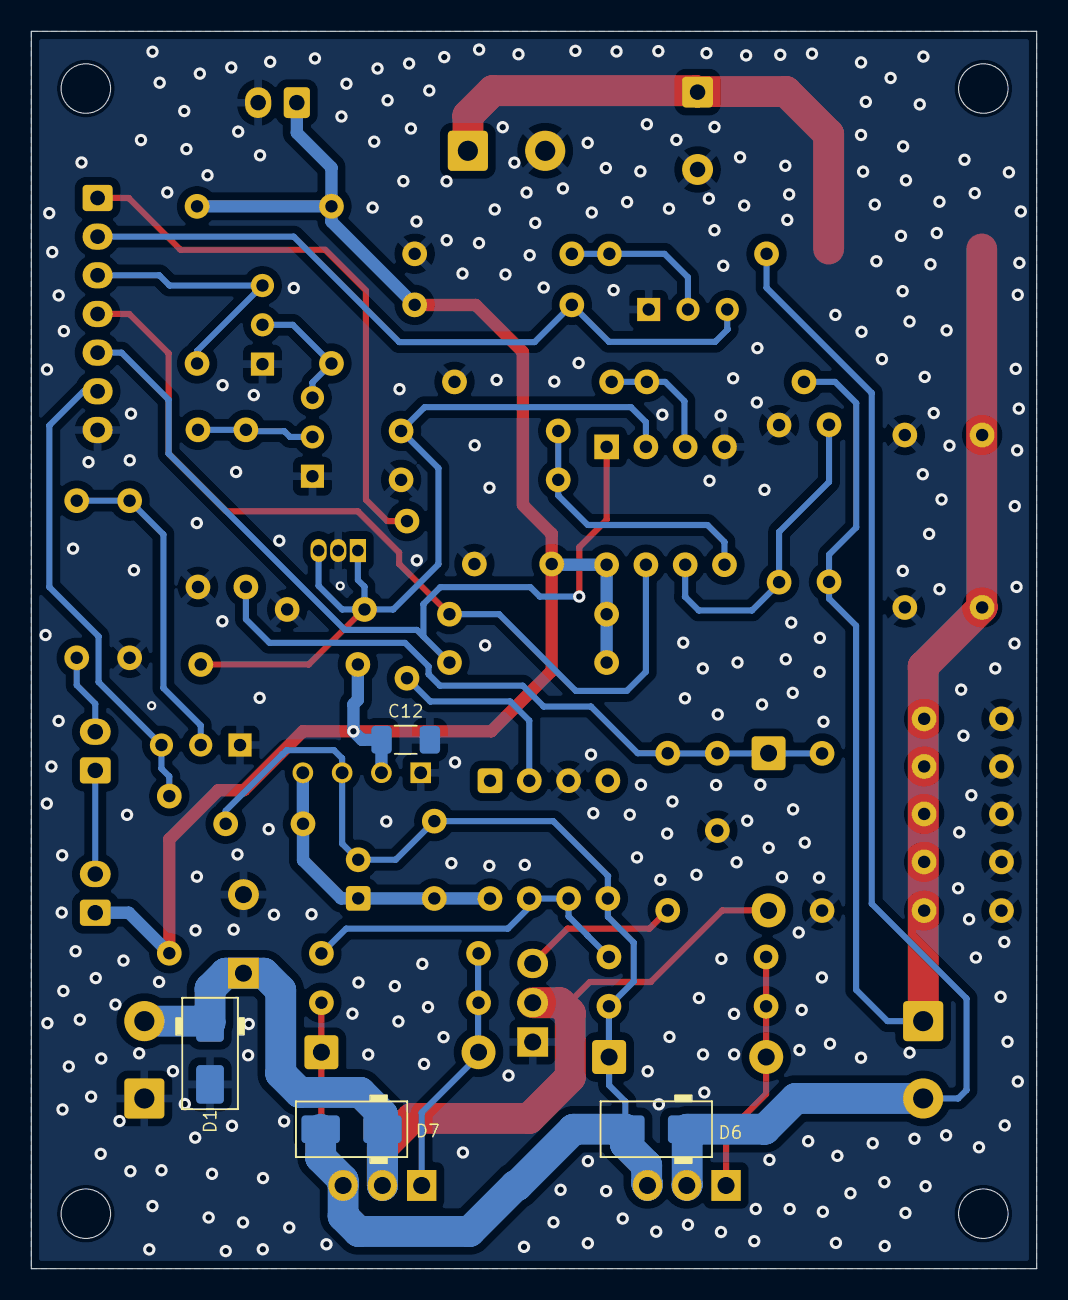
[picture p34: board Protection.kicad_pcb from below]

Board: 2 copper layers, 65.0 x 80.0 mm, 73 parts (4 on the bottom side), 30 nets.

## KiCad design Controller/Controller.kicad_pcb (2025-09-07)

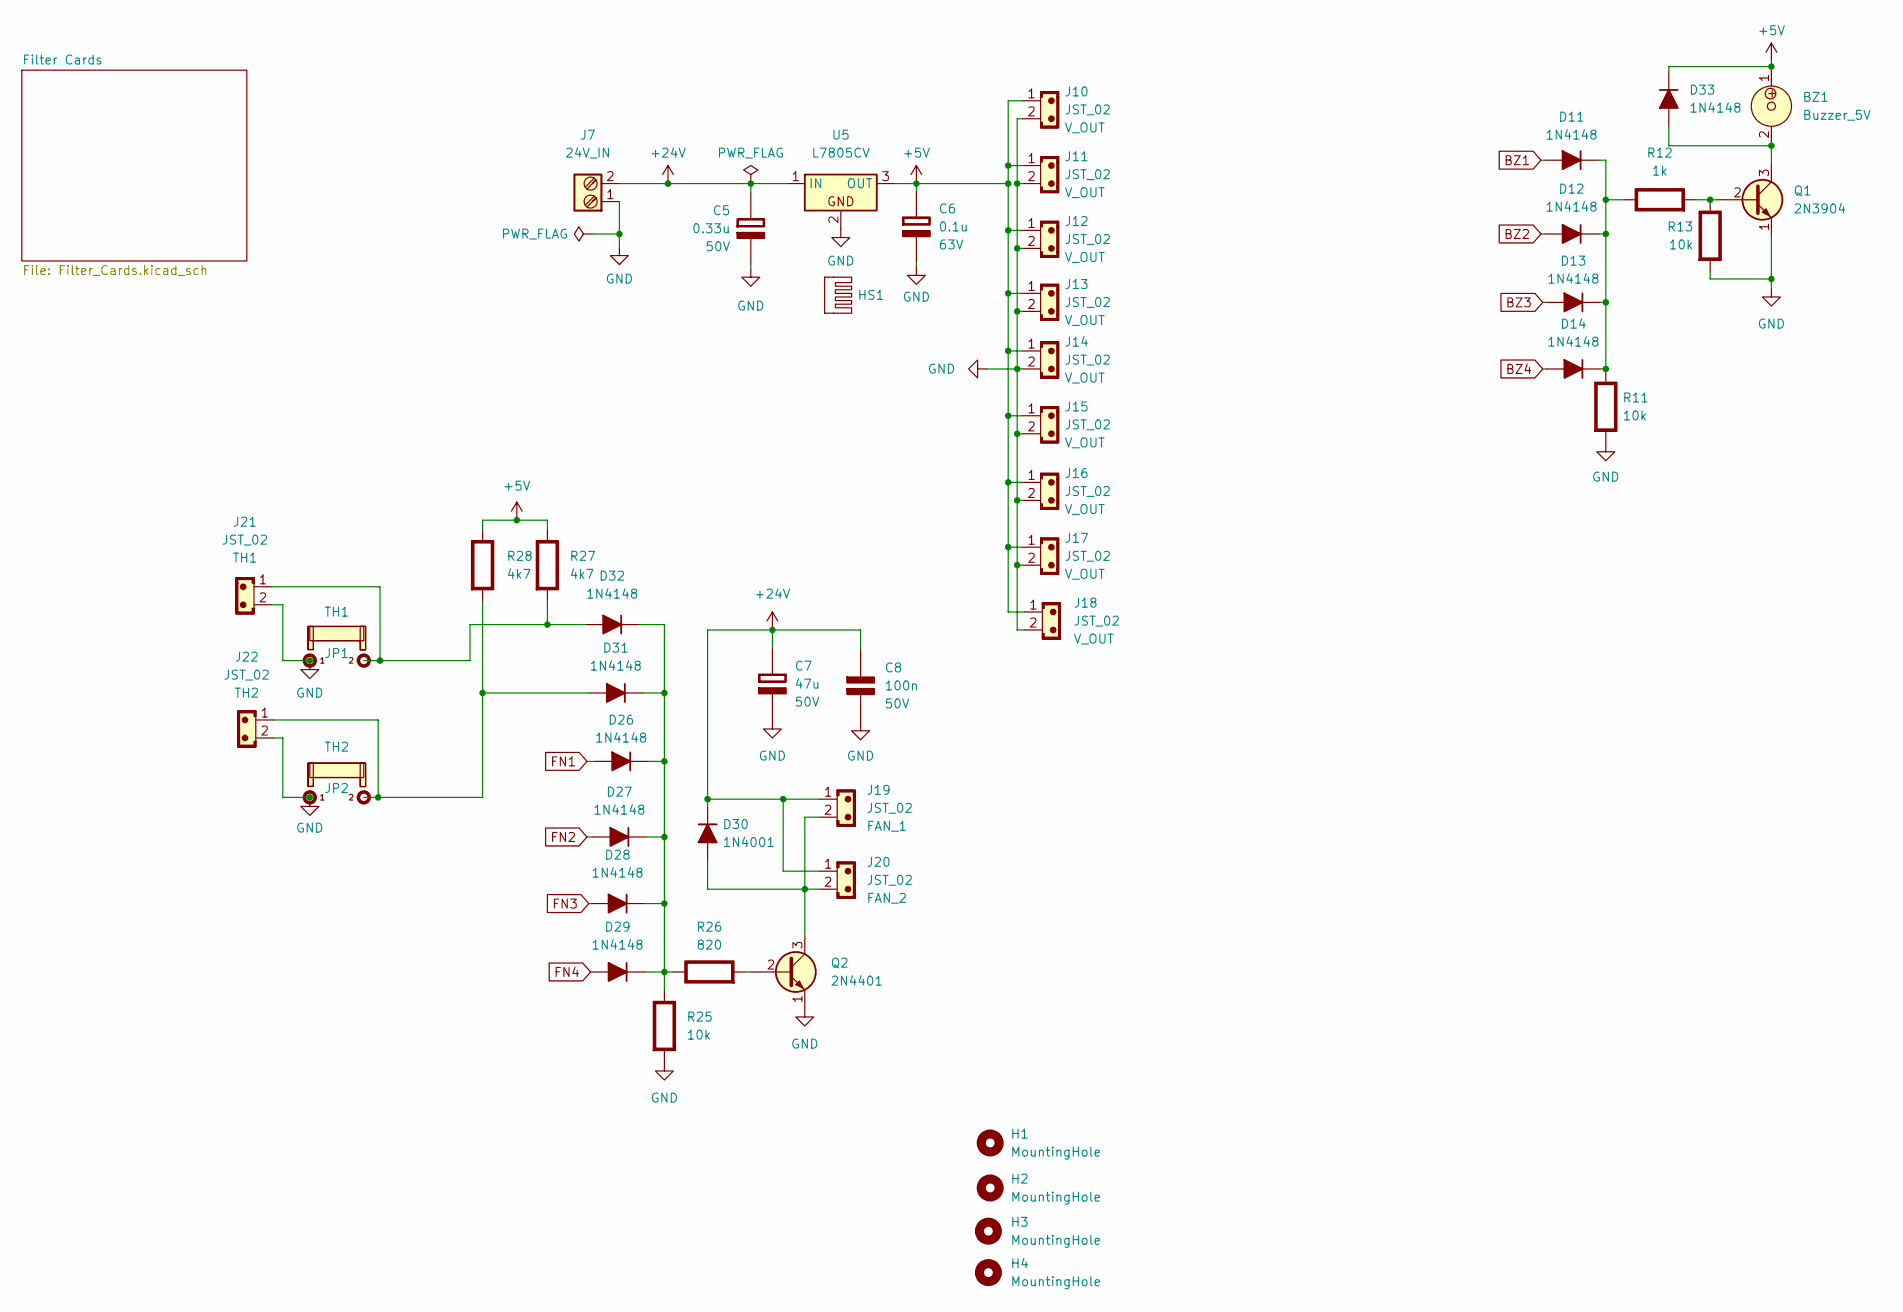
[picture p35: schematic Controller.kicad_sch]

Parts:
BZ1: Buzzer_5V; Buzzer_12x9.5RM7.6
C5: 0.33u; CP_Radial_Tantal_D5.5mm_P5.00mm; Rating 50V
C6: 0.1u; CP_Radial_Tantal_D5.5mm_P5.00mm; Rating 63V
C7: 47u; C_Radial_D6.3mm_H11.0mm_P2.50mm; Rating 50V
C8: 100n; C_Disc_D5.0mm_W2.5mm_P5.00mm; Rating 50V
D11, D12, D13, D14, D26, D27, D28, D29, D31, D32, D33: 1N4148; D_DO-35_SOD27_P7.62mm_Horizontal
D30: 1N4001; D_DO-41_SOD81_P7.62mm_Horizontal
H1, H2, H3, H4: MountingHole; MountingHole_3.2mm_M3_DIN965
HS1: Heatsink_Generic; TO-220_Heatsink
J7: Screw_Terminal_2_P5.00mm; TerminalBlock_Phoenix_PT-1,5-2-5.0-H_1x02_P5.00mm_Horizontal
J10, J11, J12, J13, J14, J15, J16, J17, J18, J19, J20, J21, J22: JST_02; JST_XH_B2B-XH-A_1x02_P2.50mm_Vertical
JP1, JP2: PinHeader_1x02_P2.54mm_Vertical
Q1: 2N3904; TO-92_Inline_Wide_EBC
Q2: 2N4401; TO-92_Inline_Wide_EBC
R11, R13, R25: 10k; R_Axial_DIN0207_L6.3mm_D2.5mm_P10.16mm_Horizontal
R12: 1k; R_Axial_DIN0207_L6.3mm_D2.5mm_P10.16mm_Horizontal
R26: 820; R_Axial_DIN0207_L6.3mm_D2.5mm_P10.16mm_Horizontal
R27, R28: 4k7; R_Axial_DIN0207_L6.3mm_D2.5mm_P10.16mm_Horizontal
U5: L7805CV; TO-220-3_Vertical

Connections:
+5V: BZ1.1, C6.1 (+), D33.1 (K), J10.1, J11.1, J12.1, J13.1, J14.1, J15.1, J16.1, J17.1, J18.1, R27.1 (+), R28.1 (+), U5.3 (OUT); also elsewhere on the board
+24V: C5.1 (+), C7.1 (+), C8.1 (+), D30.1 (K), J7.2, J19.1, J20.1, U5.1 (IN)
BZ1: D11.2 (A); also elsewhere on the board
BZ2: D12.2 (A); also elsewhere on the board
BZ3: D13.2 (A); also elsewhere on the board
BZ4: D14.2 (A); also elsewhere on the board
FN1: D26.2 (A); also elsewhere on the board
FN2: D27.2 (A); also elsewhere on the board
FN3: D28.2 (A); also elsewhere on the board
FN4: D29.2 (A); also elsewhere on the board
GND: C5.2 (-), C6.2 (-), C7.2 (-), C8.2 (-), J7.1, J10.2, J11.2, J12.2, J13.2, J14.2, J15.2, J16.2, J17.2, J18.2, J21.2, J22.2, JP1.1, JP2.1, Q1.1 (E), Q2.1 (E), R11.2 (-), R13.2 (-), R25.2 (-), U5.2; also elsewhere on the board
unnamed: D11.1 (K), D12.1 (K), D13.1 (K), D14.1 (K), R11.1 (+), R12.1 (+)
unnamed: D26.1 (K), D27.1 (K), D28.1 (K), D29.1 (K), D31.1 (K), D32.1 (K), R25.1 (+), R26.1 (+)
unnamed: D30.2 (A), J19.2, J20.2, Q2.3 (C)
unnamed: D31.2 (A), J22.1, JP2.2, R28.2 (-)
unnamed: D32.2 (A), J21.1, JP1.2, R27.2 (-)
unnamed: BZ1.2, D33.2 (A), Q1.3 (C)
unnamed: Q1.2 (B), R12.2 (-), R13.1 (+)
unnamed: Q2.2 (B), R26.2 (-)

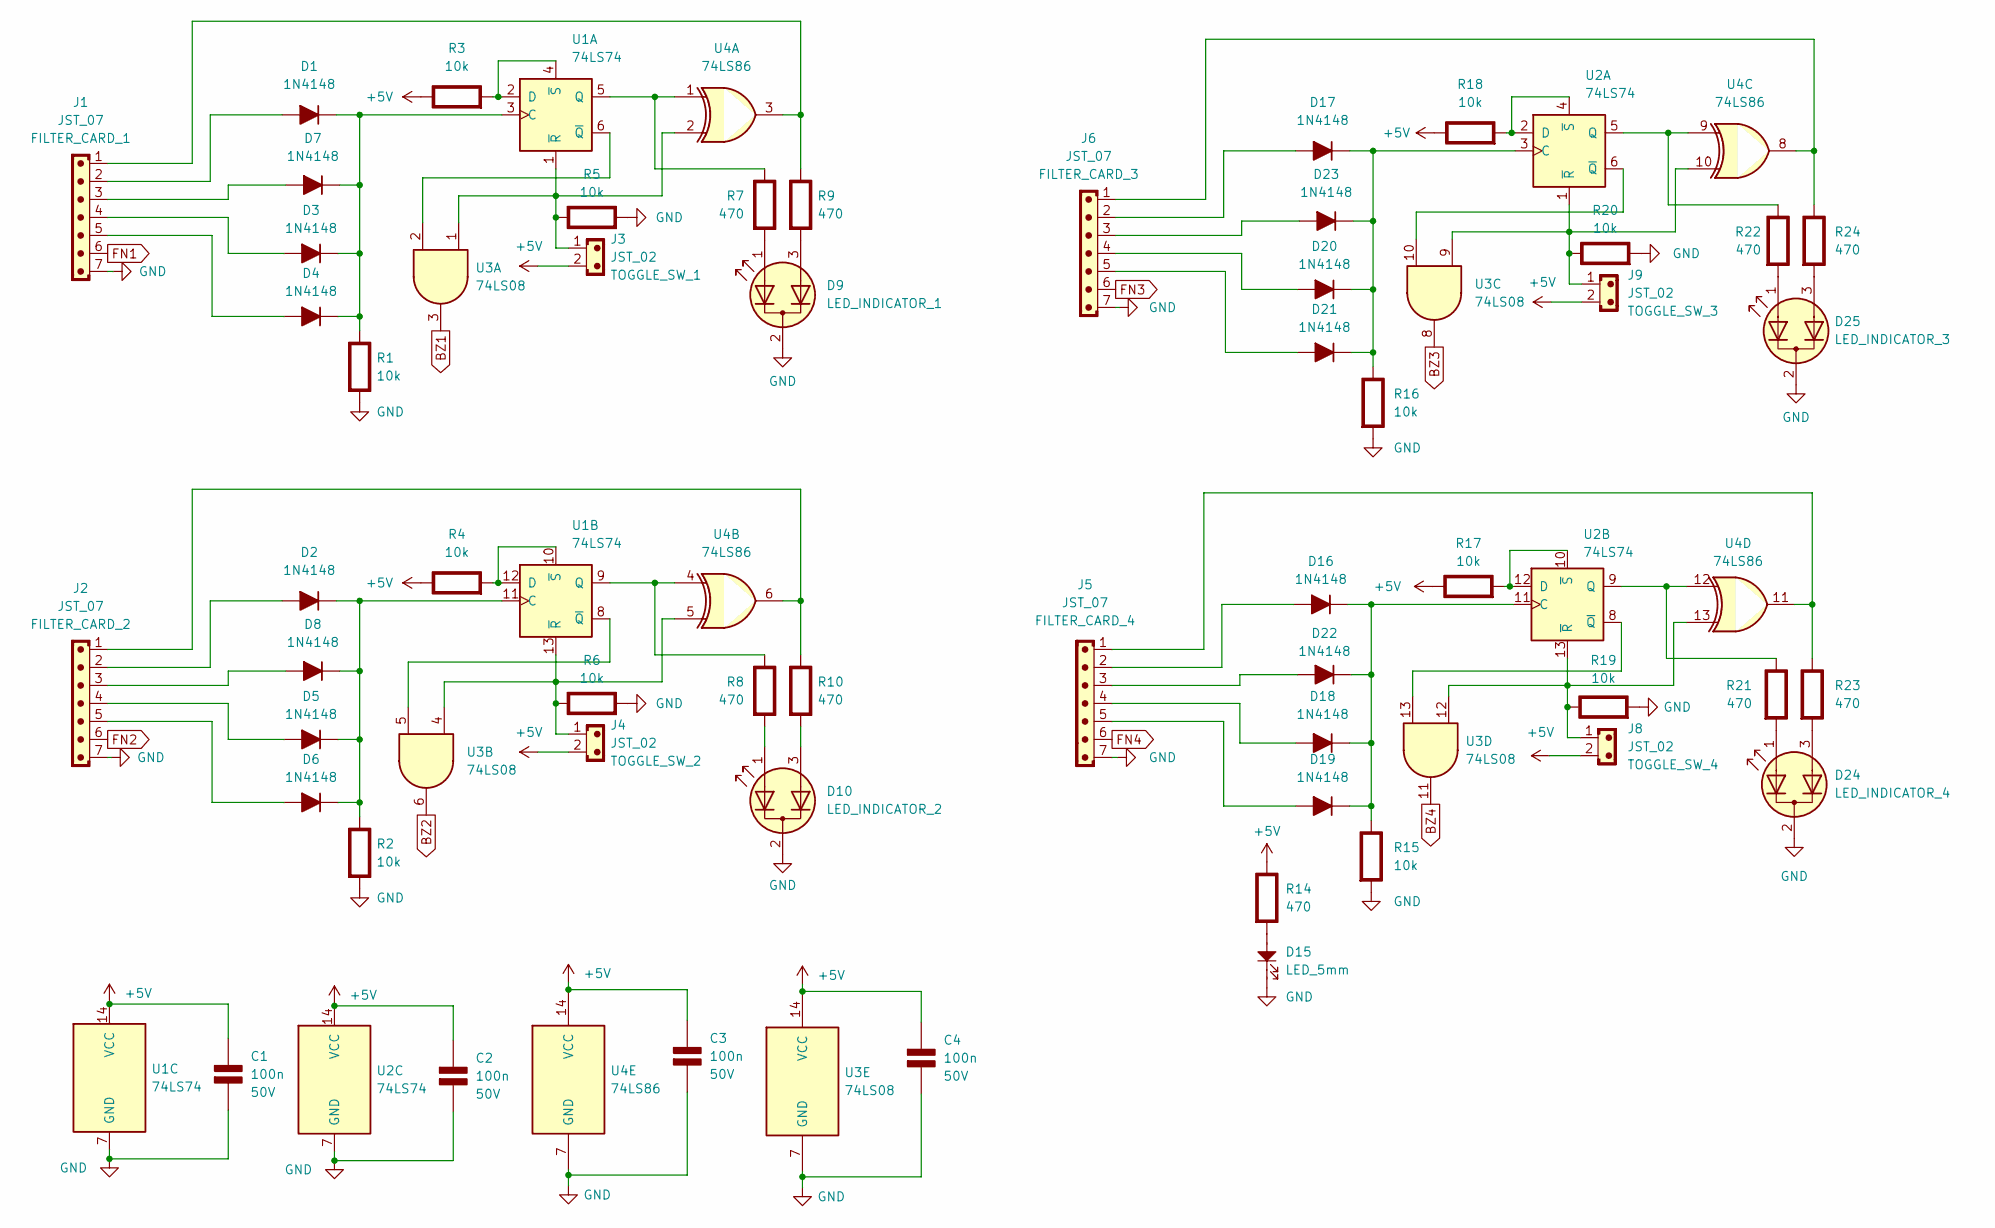
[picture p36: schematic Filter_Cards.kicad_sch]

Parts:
C1, C2, C3, C4: 100n; C_Disc_D5.0mm_W2.5mm_P5.00mm; Rating 50V
D1, D2, D3, D4, D5, D6, D7, D8, D16, D17, D18, D19, D20, D21, D22, D23: 1N4148; D_DO-35_SOD27_P7.62mm_Horizontal
D9, D10, D24, D25: LED_Dual_AKA; JST_XH_B3B-XH-A_1x03_P2.50mm_Vertical
D15: LED_5mm; JST_XH_B2B-XH-A_1x02_P2.50mm_Vertical
J1, J2, J5, J6: JST_07; JST_XH_B7B-XH-A_1x07_P2.50mm_Vertical
J3, J4, J8, J9: JST_02; JST_XH_B2B-XH-A_1x02_P2.50mm_Vertical
R1, R2, R15, R16: 10k; R_Axial_DIN0207_L6.3mm_D2.5mm_P10.16mm_Horizontal
R3, R4, R5, R6, R17, R18, R19, R20: 10k; R_Axial_DIN0207_L6.3mm_D2.5mm_P10.16mm_Horizontal; Rating %1
R7, R8, R9, R10, R14, R21, R22, R23, R24: 470; R_Axial_DIN0207_L6.3mm_D2.5mm_P10.16mm_Horizontal; Rating %1
U1, U2: 74LS74; DIP-14_W7.62mm_Socket
U3: 74LS08; DIP-14_W7.62mm_Socket
U4: 74LS86; DIP-14_W7.62mm_Socket

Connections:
+5V: C1.1 (+), C2.1 (+), C3.1 (+), C4.1 (+), J3.2, J4.2, J8.2, J9.2, R3.1 (+), R4.1 (+), R14.1 (+), R17.1 (+), R18.1 (+), U1.14 (VCC), U2.14 (VCC), U3.14 (VCC), U4.14 (VCC); also elsewhere on the board
BZ1: U3.3; also elsewhere on the board
BZ2: U3.6; also elsewhere on the board
BZ3: U3.8; also elsewhere on the board
BZ4: U3.11; also elsewhere on the board
FN1: J1.6; also elsewhere on the board
FN2: J2.6; also elsewhere on the board
FN3: J6.6; also elsewhere on the board
FN4: J5.6; also elsewhere on the board
GND: C1.2 (-), C2.2 (-), C3.2 (-), C4.2 (-), D9.2 (K), D10.2 (K), D15.1, D24.2 (K), D25.2 (K), J1.7, J2.7, J5.7, J6.7, R1.2 (-), R2.2 (-), R5.2 (-), R6.2 (-), R15.2 (-), R16.2 (-), R19.2 (-), R20.2 (-), U1.7 (GND), U2.7 (GND), U3.7 (GND), U4.7 (GND); also elsewhere on the board
unnamed: D1.2 (A), J1.2
unnamed: D1.1 (K), D3.1 (K), D4.1 (K), D7.1 (K), R1.1 (+), U1.3 (C)
unnamed: D2.2 (A), J2.2
unnamed: D2.1 (K), D5.1 (K), D6.1 (K), D8.1 (K), R2.1 (+), U1.11 (C)
unnamed: D3.2 (A), J1.4
unnamed: D4.2 (A), J1.5
unnamed: D5.2 (A), J2.4
unnamed: D6.2 (A), J2.5
unnamed: D7.2 (A), J1.3
unnamed: D8.2 (A), J2.3
unnamed: D9.1 (A1), R7.2 (-)
unnamed: D9.3 (A2), R9.2 (-)
unnamed: D10.1 (A1), R8.2 (-)
unnamed: D10.3 (A2), R10.2 (-)
unnamed: D16.2 (A), J5.2
unnamed: D16.1 (K), D18.1 (K), D19.1 (K), D22.1 (K), R15.1 (+), U2.11 (C)
unnamed: D17.2 (A), J6.2
unnamed: D17.1 (K), D20.1 (K), D21.1 (K), D23.1 (K), R16.1 (+), U2.3 (C)
unnamed: D18.2 (A), J5.4
unnamed: D19.2 (A), J5.5
unnamed: D20.2 (A), J6.4
unnamed: D21.2 (A), J6.5
unnamed: D22.2 (A), J5.3
unnamed: D23.2 (A), J6.3
unnamed: D24.1 (A1), R21.2 (-)
unnamed: D24.3 (A2), R23.2 (-)
unnamed: D25.1 (A1), R22.2 (-)
unnamed: D25.3 (A2), R24.2 (-)
unnamed: R3.2 (-), U1.2 (D), U1.4 (~S)
unnamed: R4.2 (-), U1.10 (~S), U1.12 (D)
unnamed: J3.1, R5.1 (+), U1.1 (~R), U3.1, U4.2
unnamed: J4.1, R6.1 (+), U1.13 (~R), U3.4, U4.5
unnamed: R7.1 (+), U1.5 (Q), U4.1
unnamed: R8.1 (+), U1.9 (Q), U4.4
unnamed: J1.1, R9.1 (+), U4.3
unnamed: J2.1, R10.1 (+), U4.6
unnamed: D15.2, R14.2 (-)
unnamed: R17.2 (-), U2.10 (~S), U2.12 (D)
unnamed: R18.2 (-), U2.2 (D), U2.4 (~S)
unnamed: J8.1, R19.1 (+), U2.13 (~R), U3.12, U4.13
unnamed: J9.1, R20.1 (+), U2.1 (~R), U3.9, U4.10
unnamed: R21.1 (+), U2.9 (Q), U4.12
unnamed: R22.1 (+), U2.5 (Q), U4.9
unnamed: J5.1, R23.1 (+), U4.11
unnamed: J6.1, R24.1 (+), U4.8
unnamed: U1.6 (~Q), U3.2
unnamed: U1.8 (~Q), U3.5
unnamed: U2.6 (~Q), U3.10
unnamed: U2.8 (~Q), U3.13

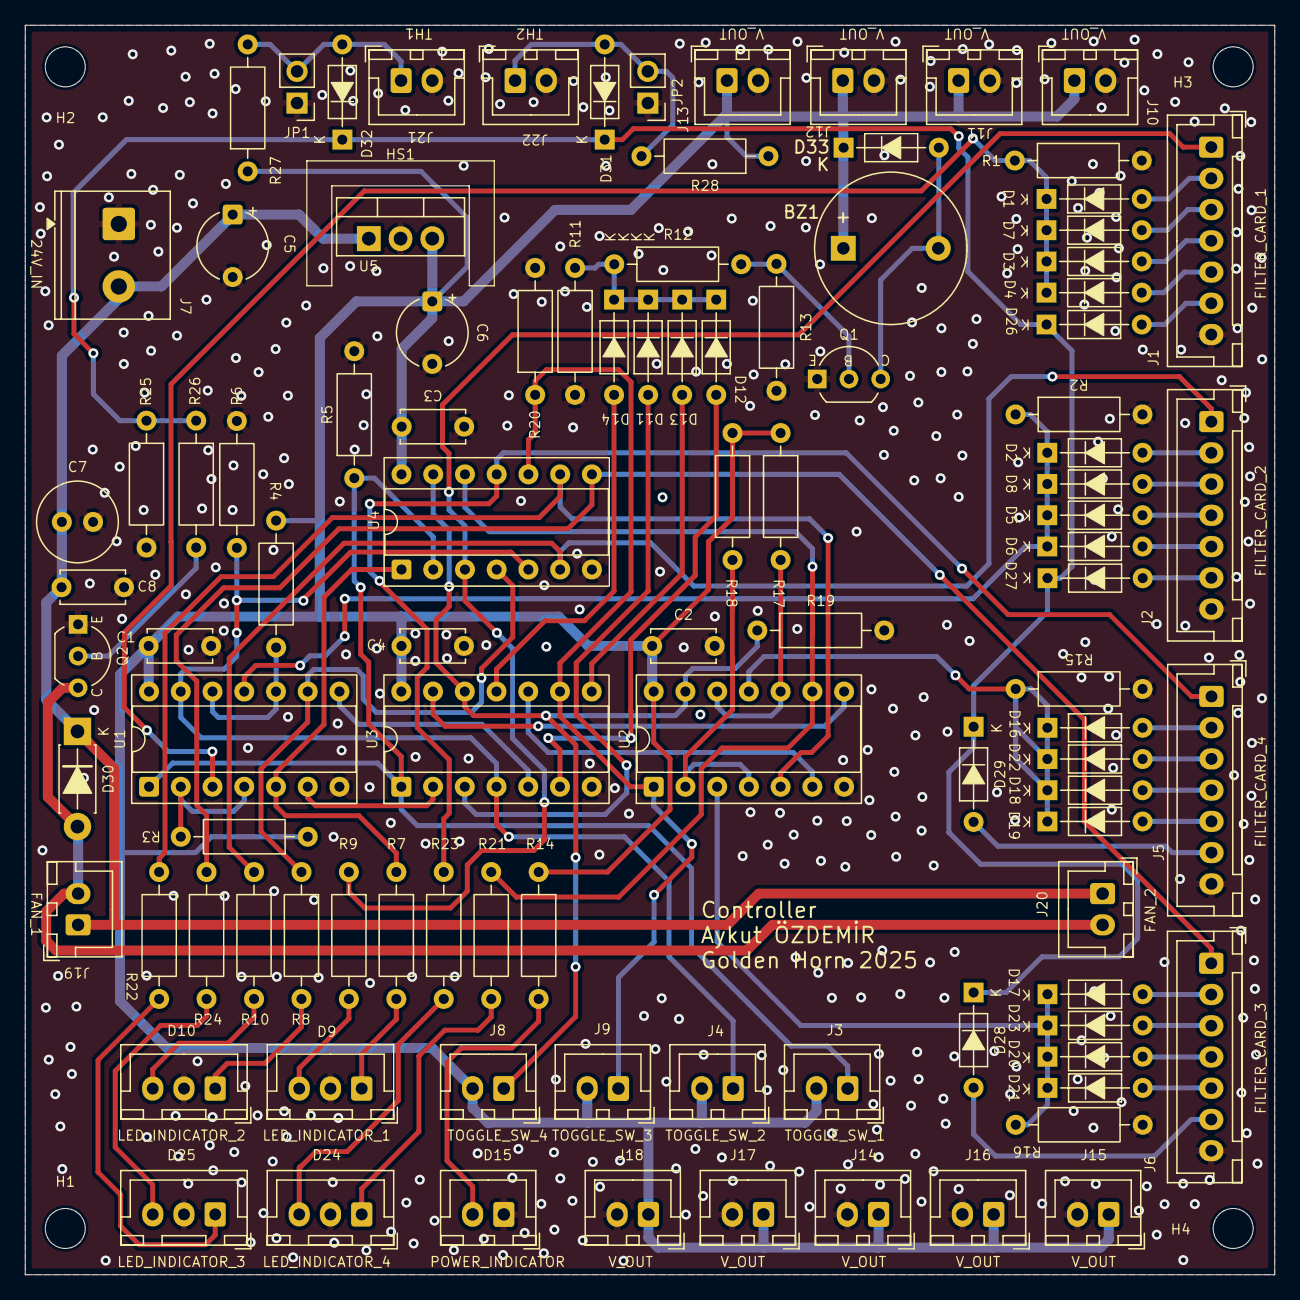
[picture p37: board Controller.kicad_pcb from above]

Board: 2 copper layers, 100.0 x 100.0 mm, 106 parts (0 on the bottom side), 68 nets.

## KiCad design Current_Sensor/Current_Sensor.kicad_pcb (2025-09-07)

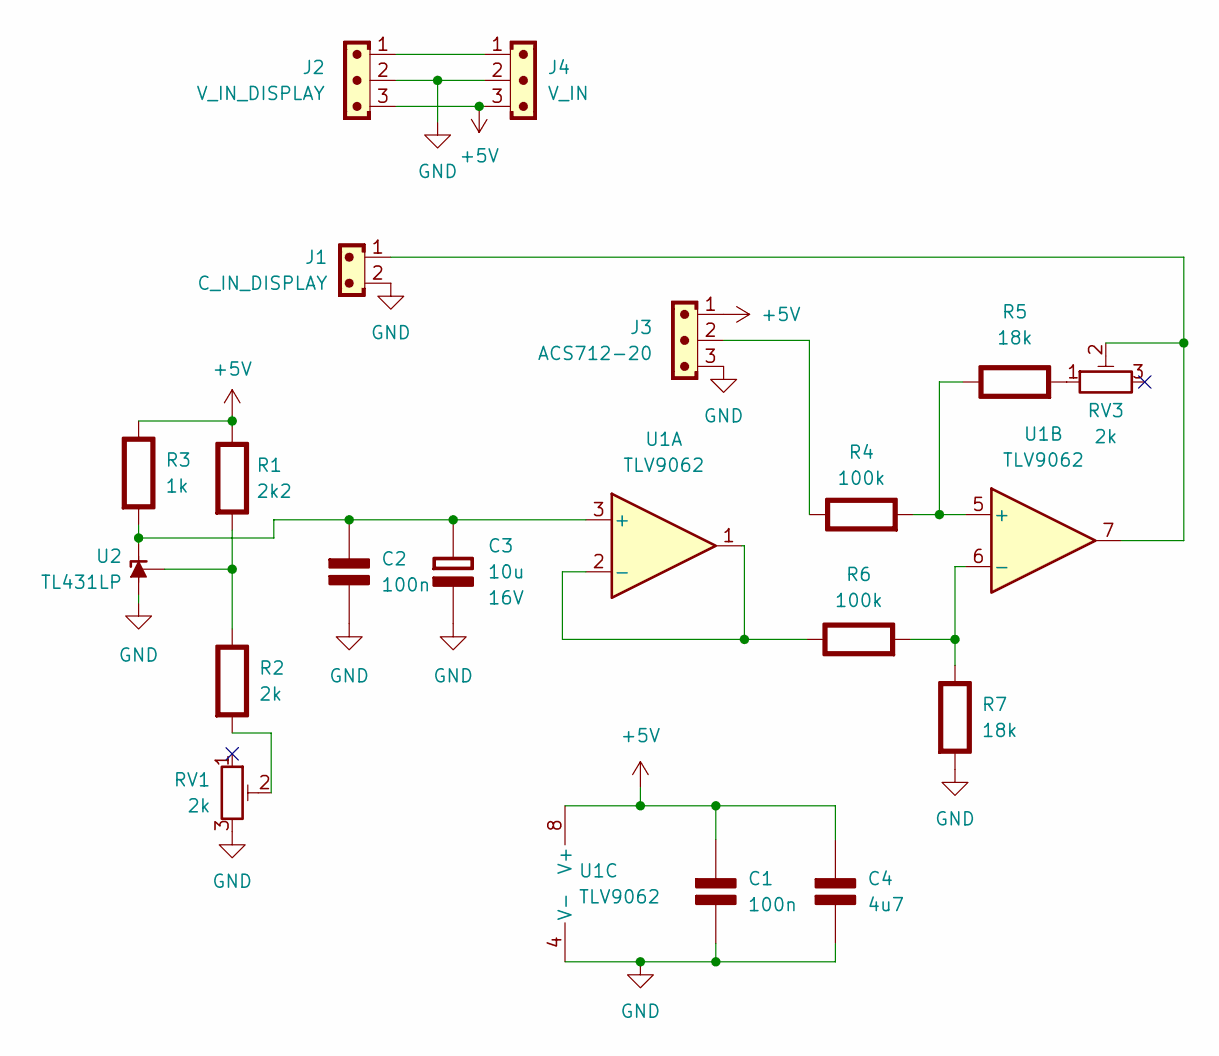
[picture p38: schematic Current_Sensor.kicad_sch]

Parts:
C1, C2: 100n; C_Disc_D5.0mm_W2.5mm_P5.00mm; Rating 50V
C3: 10u; CP_Radial_Tantal_D4.5mm_P5.00mm; Rating 16V
C4: 4u7; C_Disc_D5.0mm_W2.5mm_P5.00mm; Rating 50V
J1: C_IN_DISPLAY; PinHeader_1x02_P2.54mm_Vertical
J2: V_IN_DISPLAY; PinHeader_1x03_P2.54mm_Vertical
J3: ACS712-20; PinHeader_1x03_P2.54mm_Vertical
J4: V_IN; JST_XH_B3B-XH-A_1x03_P2.50mm_Vertical
R1: 2k2; R_Axial_DIN0204_L3.6mm_D1.6mm_P7.62mm_Horizontal
R2: 2k; R_Axial_DIN0204_L3.6mm_D1.6mm_P7.62mm_Horizontal
R3: 1k; R_Axial_DIN0204_L3.6mm_D1.6mm_P7.62mm_Horizontal
R4: 100k; R_Axial_DIN0204_L3.6mm_D1.6mm_P7.62mm_Horizontal; Rating %1
R5, R7: 18k; R_Axial_DIN0204_L3.6mm_D1.6mm_P7.62mm_Horizontal; Rating %1
R6: 100k; R_Axial_DIN0309_L9.0mm_D3.2mm_P15.24mm_Horizontal; Rating %1
RV1, RV3: 2k; Potentiometer_Bourns_3296W_Vertical
U1: TLV9062; DIP-8_W7.62mm_Socket
U2: TL431LP; TO-92_Inline

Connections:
+5V: C1.1 (+), C4.1 (+), J2.3, J3.1, J4.3, R1.1 (+), R3.1 (+), U1.8 (V+)
GND: C1.2 (-), C2.2 (-), C3.2 (-), C4.2 (-), J1.2, J2.2, J3.3, J4.2, R7.2 (-), RV1.3, U1.4 (V-), U2.2 (A)
unnamed: C2.1 (+), C3.1 (+), R3.2 (-), U1.3 (+), U2.3 (K)
unnamed: J1.1, RV3.2, U1.7
unnamed: J2.1, J4.1
unnamed: R1.2 (-), R2.1 (+), U2.1 (REF)
unnamed: R2.2 (-), RV1.2
unnamed: J3.2, R4.1 (+)
unnamed: R4.2 (-), R5.1 (+), U1.5 (+)
unnamed: R5.2 (-), RV3.1
unnamed: R6.1 (+), U1.1, U1.2 (-)
unnamed: R6.2 (-), R7.1 (+), U1.6 (-)

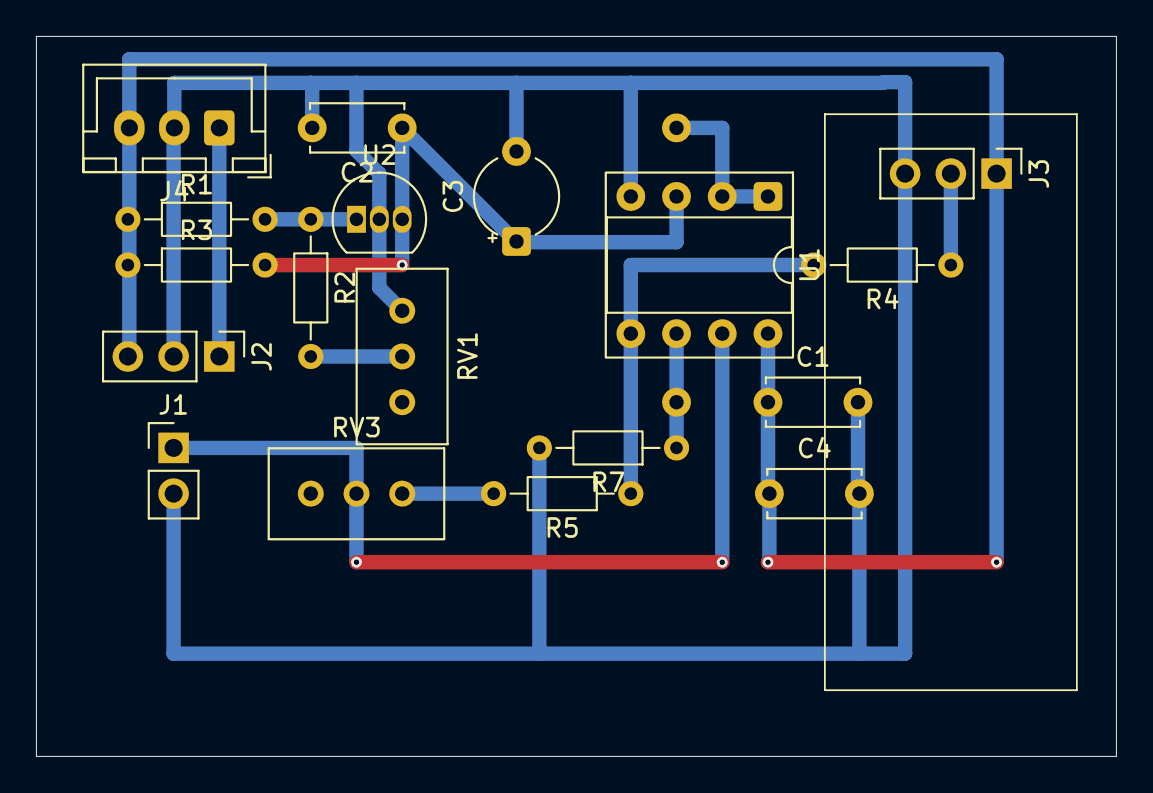
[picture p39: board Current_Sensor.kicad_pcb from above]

Board: 2 copper layers, 60.0 x 40.0 mm, 19 parts (1 on the bottom side), 12 nets.

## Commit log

2025-09-07 Circuit design
    [Controller-B_Courtyard.gbr, Controller-B_Cu.gbl, Controller-B_Fab.gbr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]
2025-09-07 3D design
    [AC 3-Pin With Fuse.stp, Banana jack (4mm).stp, Bourns 3590S-291-103L.step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]
2025-09-07 Undervoltage protection fixed for adj ch
    [Protection-B_Courtyard.gbr, Protection-B_Cu.gbl, Protection-B_Fab.gbr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]
2025-09-07 3D design completed
    [Tasarım_nested.dxf]
